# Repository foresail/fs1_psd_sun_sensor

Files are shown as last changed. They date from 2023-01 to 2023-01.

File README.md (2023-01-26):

# Foresail-1 PSD Sun Sensor

This repository contains the public available design files for the PSD sun sensor designed for the Foresail-1 Cubesat.

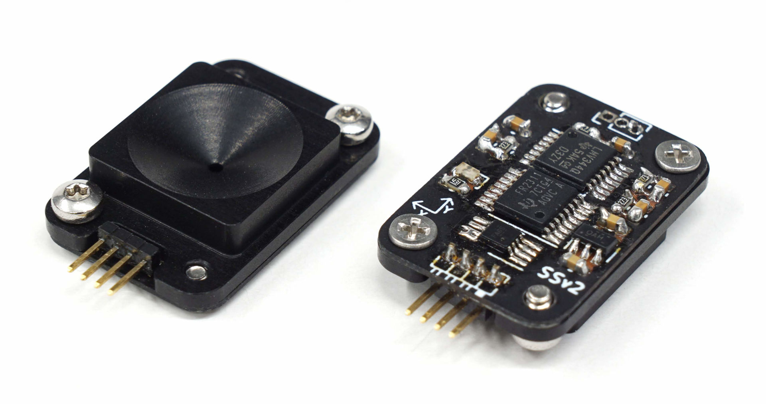
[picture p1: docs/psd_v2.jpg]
PSD Sun Sensor Prototype v2


The general characteristics of sensor design are:
- Dimensions: 24 mm × 16 mm × 6 mm
- Mass: 4 grams
- Panel mountedable into 14x14 mm hole with two M2 screws.
- Electrical connection by soldering on the panel PCB or by harness.
- FOV: ~100 degrees, resolution: 0.13°, accuracy: ±1° (discussed in the desgin document)
- Refresh rate up to 100 Hz. (Sampling time: 4 ms + communication overhead)
- Can provide following data products:
    - Raw current measurements
    - Point & intensity measurements
    - Sun vector & intensity measurements
    - Angles & intensity measurements
- I2C digital serial interface (hardware version 3)
- RS-485 digital interface (hardware version 4)
- Low power consumption < 4 mW when active
- Nominal operating voltage: 3.6 - 3.8V: Can be extened easily to 2.0 – 5.5 V.

## Documentation

- [FS1 ADCS PSD Sun Sensor Design Document](docs/FS1_ADCS_PSD_Sun_Sensor_Design_Document.pdf)
- [Version 3 schematic (I2C variant)](v3/v3_schema.pdf)
- [Version 3 firmware source code](v3/fw)
- [Version 4 schematic (RS-485 variant)](v4/v4_schema.pdf)
- [Calibration and test tools for PC](calibration)
- [Mechanical design files](mechanical)

## Licence

The design is licenced under [CERN Open Hardware Licence Version 2](LICENCE)

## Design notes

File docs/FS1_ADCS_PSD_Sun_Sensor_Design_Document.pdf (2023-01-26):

Version date: 2023-01-26
Responsible: Petri Niemelä
Document name: FS1 ADCS PSD Sun Sensor Design Document

# Foresail-1

# PSD Sun Sensor Design Document

# Aalto University

## Department of Electronics and Nanoengineering

## PSD Sun Sensor Design Document

FS1 ADCS PSD Sun Sensor Design Document
Page: 2 / 22

### Authors

Name | Worked with parts
Petri Niemelä | The whole document

Approved by

______________________________________

Page: 3 / 22

### Table of Contents

1 General | 4
1.1 Scope | 4
1.2 Applicable Documents | 4
1.3 Reference documents | 4
1.4 Abbreviations and acronyms | 4
2 Sensor Design | 5
2.1 Performance | 6
2.2 Sun vector estimation | 9
3 Electrical Design | 10
3.1 Electrical Interface | 10
3.2 Microcontroller | 10
3.2.1 Radiation Hardening | 11
3.3 Transimpedance Amplifiers | 11
3.4 Analog Digital Converter | 14
3.5 Power supply | 14
3.6 I2C bus isolation | 14
3.7 Operating environment | 15
4 Mechanical Design | 16
4.1 Mechanical Interface | 16
5 Digital interface | 17
5.1 I2C Commanding Protocol | 17
5.2 RS-485 Commanding Protocol | 17
5.3 Command set | 17
6 References and further reading | 19
7 Appendices | 21
7.1 Schematics | 21
7.2 Bill of Material | 21
7.3 PCB layout | 22

Page: 4 / 22

## 1 General

### 1.1 Scope

This document represents a detailed design of the PSD Sun Sensor designed for FORESAIL-satellites. This document applies for hardware version v3 (I2C variant) and v4 (RS-485 variant).

The public design files can be found from Github-repository: https://github.com/foresail/fs1_psd_sun_sensor

### 1.2 Applicable Documents

[AD-01] FS1 ADCS PSD Sun Sensor Prototype Test Plan (https://docs.google.com/document/d/1LfsjXxHAqfksmW_5qAY_K_lkndrjo7vK9R7hFGDcjuA/edit)

[AD-02] FS1 ADCS PSD Sun Sensor Qualification Test Report template (https://drive.google.com/open?id=1y2Mrd9W40DUWGKvcDPNy5vSXA1CmaDOZ_xgLSq9taWw)

### 1.3 Reference documents

[RD-01] Hamamatsu S5990-01 Two-Dimensional PSD
datasheet: https://www.hamamatsu.com/resources/pdf/ssd/s5990-01_etc_kpsd1010e.pdf

[RD-02] Texas Instrument’s MSP430FR231x Mixed-Signal Microcontrollers datasheet: http://www.ti.com/lit/ds/slase58d/slase58d.pdf

[RD-03] Texas Instrument’s OPAx340 Single-Supply, Rail-to-Rail Operational Amplifiers datasheet: http://www.ti.com/lit/ds/symlink/opa4340.pdf

### 1.4 Abbreviations and acronyms

ADC | Analog-to-Digital Converter
FRAM | Ferroelectric Random Access Memory
FOV | Field Of View
MCU | Microcontroller
PCB | Printed Circuit Board
PSD | Position Sensitive Detector/Device
TIA | Transimpedance Amplifier
WDT | Watchdog Timer

Page: 5 / 22

## 2 Sensor Design

The PSD sensor (Position Sensitive Detector/Device/Diode) is a light sensitive photodiode which produces a small current when exposed to light. The PSD differs from the normal photodiode by having four cathodes and one anode for one single large detector area. When the sensitive area is illuminated with a relatively small spot of light the produced currents are distributed depending on the position of the light spot. When the light spot is created using a pinhole structure the sensor can be used to measure direction/angle of the incoming light and thus the concept can be applied for making a sun sensor.

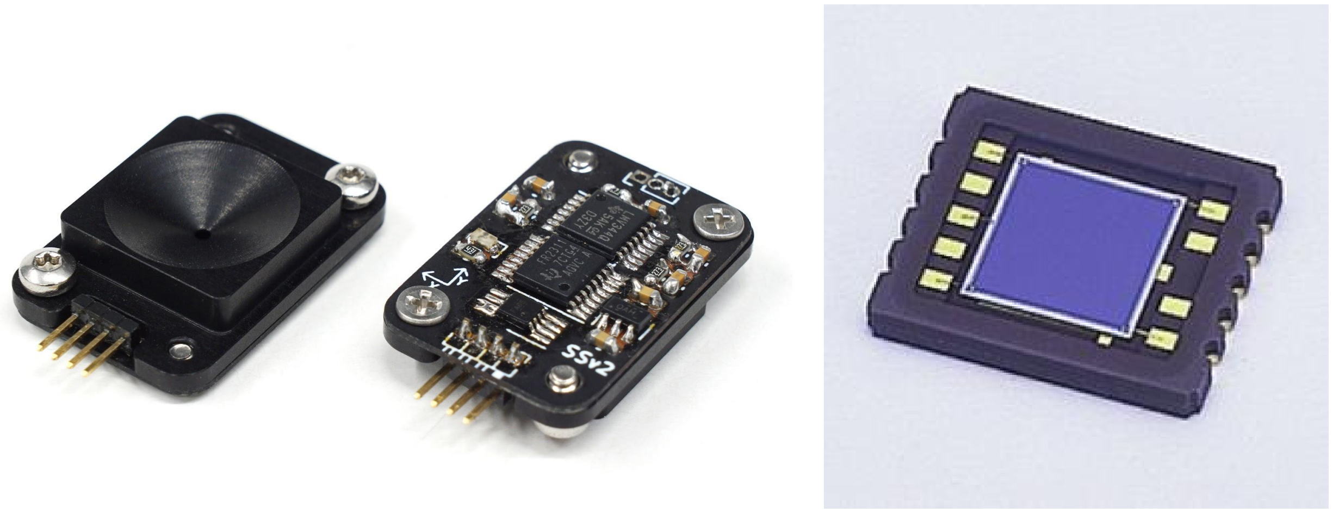
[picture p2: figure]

Figure 1: PSD Sun Sensor version 2 and Hamamatsu S5990-01 Position Sensitive Device

The used PSD, Hamamatsu S5990-1, (In Figure 1) is so called tetra-lateral type (pin-cushion type) that delivers improved position detection and linearity compared to other similar diodes. The sensor has a large 4 × 4 mm active area. [RD-01]

PSD sensors advantages in sun sensor application can be considered: simple electrical and mechanical design and easily achievable large Field of View (FOV). The sensor design's largest disadvantage is its sensitivity for straylight meaning that the sensor cannot discriminate between direct sunlight and reflected sunlight. Reflections, for example from moonshine or earthshine, cause bias error which cannot be easily eliminated from the measurements. Effect of this will be discussed later in detail.

The general characteristics of sensor design are:
- Dimensions: 24 mm × 16 mm × 6 mm
- Mass: 4 grams
- Panel mountable into 14x14 mm hole with two M2 screws
- Extension behind the panel: 3.1 mm
- Electrical connection by soldering on the panel PCB or by harness.
- FOV: ~100 degrees, resolution: 0.13°, accuracy: ±1° (discussed in the following sections)
- Refresh rate up to 100 Hz. (Sampling time: 4 ms + communication overhead)
- Can provide following data products:
- Raw current measurements
- Point & intensity measurements
- Sun vector & intensity measurements
- Angles & intensity measurements

Page: 6 / 22

- I

2C digital serial interface (applicable for hardware version 3)
- Maximum bus speed 400 kHz at 3.3V logic level.
- I

2C address can be configured via the command interface.
- The I²C bus is isolated when the sensor is unpowered.
- RS-485 digital interface (applicable for hardware version 4)
- Follows reduced Foresail multi-drop RS-485 protocol definition
- TBD
- Low power consumption < 4 mW
- Sleep: 0.45 mA @3.6 V
- Sampling: 0.9 mA @3.6 V
- Peak sampling: TBD mA @3.6V
- In-rush current: TBD mA @3.6V
- Operating voltage: 2.0 – 5.5 V
- The standard version has a 3.3V LDO and designed operating voltage is around 3.6V.
- MSP430 can operate with voltages down to 1.8 V.

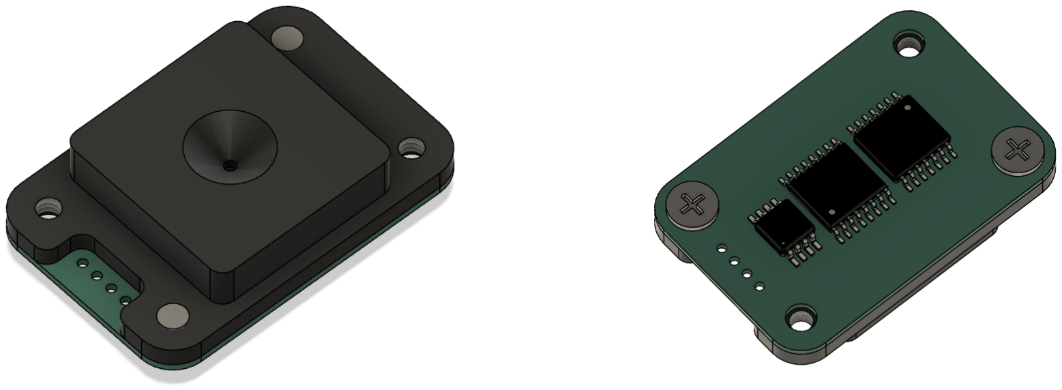
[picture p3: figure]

Figure 2: Front and back side of the PSD Sun Sensor assembly from CAD program.

### 2.1 Performance

The performance (FOV and accuracy) of the sensor is mainly determined by the geometry of the pinhole structure. The pinhole geometry is illustrated in the following figure. By adjusting the distance of the pinhole from the sensor. On the Foresail-1 PSD Sun Sensor the distance from photodiode to pin hole is 1.50 mm.

Page: 7 / 22

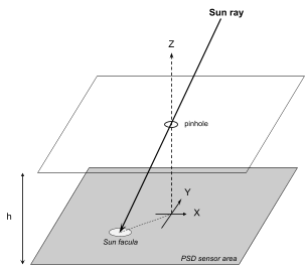
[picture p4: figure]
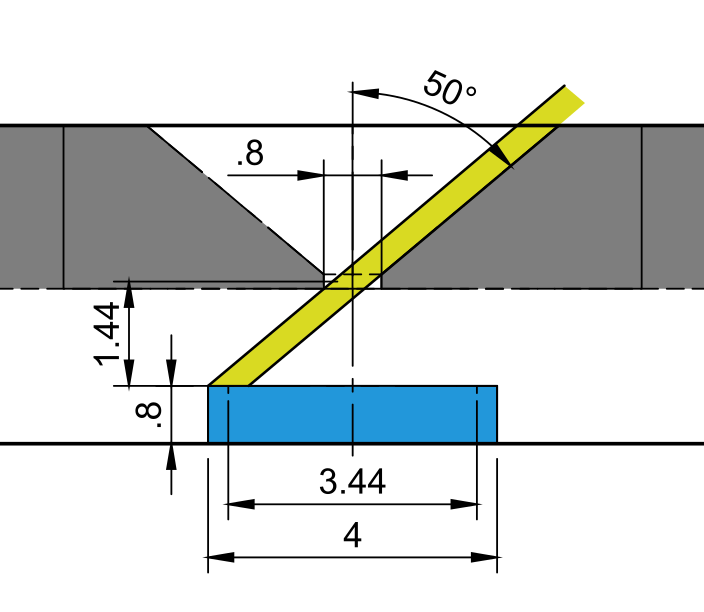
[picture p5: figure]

Figure 3: On left the sensor’s pinhole geometry illustrated in 3D. On the right the sensor’s actual pin hole geometry with dimensioning.

Field of View:
The maximum field of view of the sensor is determined by its tan( FoV/2 ) =

0.5*(w − d)
ℎ | =

0.5 * 3.44 mm
1.44 mm

⇒ FoV = 100°
In practice the sensor has an even larger FOV. (see calibration results)

Resolution:
When using 10 bits (1024 counts) per channel and because there are two channels per axis, each axis is “sampled” in 11-bit resolution. Thus, at the center of the sensor the theoretical resolution is:

θ = atan(

| (3.44 mm / 1024)
| 1.44 mm

) ≃ 0. 134°

This resolution improves when moving toward the edge of the sensor. Smaller angle changes in the Sun direction causes larger changes in light spot position. At the edge the theoretical resolution is:

θ = atan(

0.5 * 3.44 mm
1.44 mm

) − atan(

0.5 * 3.44 mm * 511/512
1.44 mm

) ≃ 0. 055°

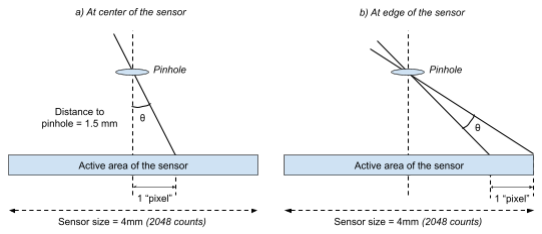
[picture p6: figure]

Figure 4: Resolution estimated using simplified pin hole geometry.

In theory, the resolution doesn’t depend on the size of the light spot until the light spot is clipped by

Page: 8 / 22

the edge of the active area of the sensor. The output currents and the current distribution depends on the intensity of the light and the “mass center” of the light. If the light spot size is increased its mass center stays the same. Only the intensity (amount of light passing through the pinhole) changes. The sensor’s gain can be adjusted using for any pinhole

Real accuracy:
In theory the sensor could achieve better than 0.15° accuracy but in practice the accuracy is not that good and it is affected by numerous error sources. In this section some of those error sources are analyzed. In practice the resolution of PSD based sensors varies between around 1 - 5°. If someone claims better accuracy (with similar FOV and single sensor) than this when using the same sensor technology, they most likely lie or don't tell the whole truth.

Error sources:
1) The sensor cannot differentiate between different sources of light: Sun, moon, Earth’s Albedo, specular reflections from the Earth’s surface. Discussed in detail in the next section.
2) The pinhole structure is not a perfect pinhole. Incoming light can reflect from the edge hole and cast a second light spot. Black anodisation aims to cope with this problem.
3) At high angles the cover glass can refract the light spot. This effect can be partially calibrated.
4) The light spot can reflect from the cover glass and bounce inside the sensor. The error caused by the reflections inside the sensors are tried to minimize by anodizing the sensor cover black.
5) The response of the PSD is not completely linear aka current distribution doesn’t map the light spot position perfectly. This happens both in axis and diagonally mapping. Hamamatsu’s tetra-lateral type (pin-cushion type) PSD aims to compensate for this.
6) The ADC is not perfect and it has noise on its results. According to the MCU’s datasheet ADC Effective error in 10-bit mode is ±2 LSB (least significant bits). Based on this the accuracy is less than 0.3°. ADC noise could be reduced by using oversampling because the sampling noise is gaussian by its nature. This is not seen beneficial because other error sources are more dominant and multi-sampling would just slow down the sampling.
7) Thermal expansion of the components is not considered. The surface temperature of the satellite can vary between -40°C and 40°C. The sensor cover should have a mirror finish on its front side to minimize heat load.
8) Sensor mounting on the satellite structure easily introduces a significant systematic error which is larger than the accuracy of the sensor. Calibrating the sensor position/orientation relative to the satellite’s coordinate system should be performed after final assembly but such test setup is not simple.

Effect of the straylight:
PSD sun sensor's greatest disadvantage is its incapability to differentiate between different light sources. The currents generated by different light sources (Sun, Earth, Moon shine and specular reflections from Earth’s surface) sums up together and cannot be separated from each other. Thus, Earth’s and Moon’s albedos add a bias error into Sun direction estimation if they are visible at the same time. Because each satellite’s face has a dedicated sun sensor and only the strongest signal is taken into consideration in sun vector determination, the Earth’s albedo affects the sun vector measurements only when the Sun and Earth are inside the same 90° FOV “pyramide”. This happens

Page: 9 / 22

when the satellite is above 66’th latitude (north or south) and ±24° around the termination zone. The influence of Earth’s albedo is constantly on sun synchronous orbit, which Mean Local Time of the Ascending Node (LTAN) is between 04:24 - 08:36 and 16:36 - 19:24. These regions are illustrated in the Figure 5.

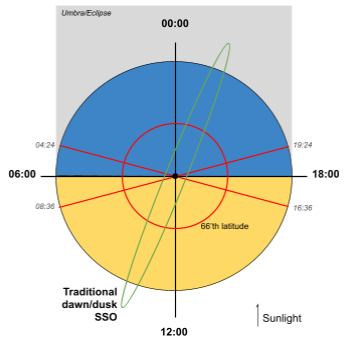
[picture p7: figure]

Figure 5: Orbit regions where PSD’s operation is affected by Earth’s albedo.

The effect of Earth’s albedo to the accuracy of PSD sun sensor is greatly discussed in Rober Valner’s bachelor’s thesis: http://dspace.ut.ee/bitstream/handle/10062/30981/Robert_Valner.pdf In his thesis he concludes that: “the net uncertainty of the measurements of the sensor is 2.5° with coverage probability of approximately 95%”

Intensity accuracy:
The intensity measurement of the sensor is relative and should not be used as absolute measurement. The sensor’s intensity output is the average of each channel's output in range from 0 to 1024. The reading highly depends on the sensor’s temperature due to photodiodes efficiency characteristics and temperature drift of the voltage reference.

The intensity reading itself could be also used to determine the sun angle using inverse cosine law and with temperature compensation using the MCU’s temperature sensor could provide better absolute accuracy but this is implemented because it’s not seen beneficial for an attitude control system as whole. The linearity of the intensity measurement is not known.

What could be improved?
Possible methods to improvement accuracy:
1. More sensors with smaller FOV
2. Add UV bandpass filter to remove the effect of albedo and specular reflections.

### 2.2 Sun vector estimation

The determination of the sun vector from multiple sun sensors can be done using following simple algorithm:

Page: 10 / 22

meas = get_all_sun_vectors()

sun_detected = false
sensor_i = arg_max(meas.intensity)
if meas[sensor_i].intensity > detection_threshold:
sun_direction = apply_rotation(sensor_i, meas[sensor_i].vector) sun detected = true

## 3 Electrical Design

The electrical design of the sensor is very simple. It consists of a PSD sensor itself (aka four channel photodiode), four transimpedance amplifiers and a MCU for analog to digital conversion and digital communication.

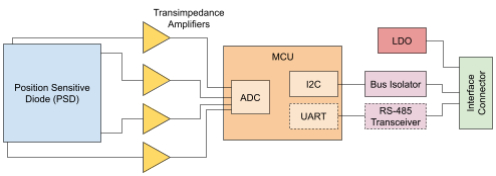
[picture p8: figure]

Figure: Block diagram of the sensor's electrical components and their connections.

### 3.1 Electrical Interface

The sensor’s electrical interface is described in the table below.

Table: Sensor pinout
Pin number | Pin name on version 3 | Pin name on version 4
1 | GND | GND
2 | VCC | VCC
3 | I2C SDA | RS-485 DATA+
4 | I2C SCL | RS-485 DATA-

On the PCB the electrical connection is done to the 1.27 mm pitch pin 4 hole connector footprint. To this footprint the electrical connection can be done by directly soldering the sensor on a PCB panel using a right angle 1.27mm pin header or by soldering a pigtail cable on it.

### 3.2 Microcontroller

The PSD sun sensors’ MCU is Texas Instrument’s MSP430FR2311IPW16. MCU’s important features are: [RD-02]

Page: 11 / 22

- Small TSSOP-16 package
- Runs at 4 MHz
- 3.75KB of Program FRAM (Radiation Resistant and Nonmagnetic) + 1KB of RAM
- Internal 1.2V voltage reference
- 8 channel 10-Bit Analog-to-Digital Converter (ADC) with internal 1.5V voltage reference
- Optimized low power modes (32nA in shutdown)
- Wide support for serial communication protocols such as I

2C, UART etc.
- Internal brown-out detection circuit

The selected MCU has also internal opamp which could have been used for something.

### 3.2.1 Radiation Hardening

Following radiation hardening are considered in the design:

### 1. Usage of system FRAM memory:

The selected MCU uses FRAM technology for storing its firmware. The FRAM technology is known from its radiation hardness on a memory cell (SEU: Single Event Upsets). This doesn’t ensure complete radiation hardness against other types of single events. Single events can also happen in the memory controllers etc.

Also the sensor is vulnerable to destructive single events burnouts if no latching.

The dose tolerance of the MCU is not known and it could be generalized outside of a single batch.

### 2. Watchdog Timer:

Watchdog resets the MCU every ~40 seconds if the main loop stops running. Heartbeat timer tries to wake up the processor every 70 ms to execute the main loop.

### 3. Register refreshing by resetting:

Sensor initializes itself every 2 minutes in nominal state to refresh all internal peripheral registers.

### 3. Component-level power cycling:

The opamp’s power is supplied from MCU’s IO-pin which works as current limiter and load switch and it can be used to cycle on every reset.

### 4. Sensor Aluminium shielding

At the surface of the satellite, the sensor experiences a harsher radiation environment compared to the rest of the electronics on board inside the radiation shielding. To compensate this a little bit, the thickness of the aluminum sensor cover has not been minimized to give some protection against total dose effects. The only way to improve this more is to move the electronics beside the PSD photodiode itself inside the satellite.

### 3.3 Transimpedance Amplifiers

For PSD sensor current measurement the sensor board has four transimpedance amplifiers (TIA) to perform current-voltage conversion with predefined gain. The amplifier gain is set by the external resistor and adjusted depending on illumination levels, hole size etc. Photodiodes are in zero reverse bias configuration for improved sensitivity at low intensities. Additionally, a filtering capacitor is placed parallel on the feedback loop to cut-off frequencies above 100 Hz.

Page: 12 / 22

When the current is zero the opamp outputs the reference voltage and higher the current lower the output voltage is. The output voltage can be then measured by the ADC. MSP430’s internal voltage reference (VREF+) is used for the opamp. The precision of the voltage reference doesn’t affect the overall point position measurements. The possible reference voltage drift affects only absolute intensity measurements and is the same for all the channels. The point position is calculated from the differences of absolute current measurement as defined in equation X, and thus, possible reference voltage drift won’t affect sun vector accuracy. The absolute illumination is not sure for sun vector determination. Also, the diode’s leakage current will vary based on the temperature.

On hardware version 4 (RS-485 variant), the MSP430’s internal voltage reference cannot be used due to pin mapping collision with an UART pin required for RS-485 transceiver. Thus, an external voltage reference is required for the opamps. There are no real requirements for the reference other than voltage should be such that the opamp doesn't need to drive till the rail voltage. Absolute stability is not required because the intensity measurements are already relative by their nature and the reference is shared between the channels. Also the voltage reference is connected to very high impedance (only opamps inputs), so the current draw is negligible. Thus, to keep the BOM and PCB layout simple a simple 1:1 resistor divider was chosen to generate 1.65 V reference. The resistor divider as voltage reference is sensitive for source voltage but in this case the 3.3V source voltage is regulated very close to the divider itself.

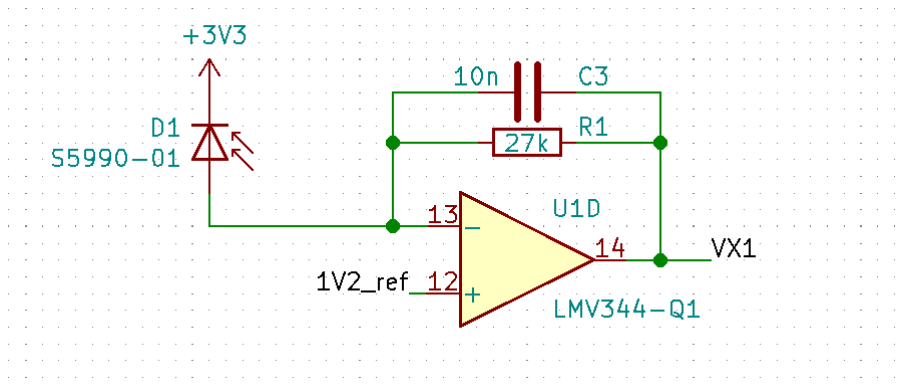
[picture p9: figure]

Figure 6: Simplified circuit diagram of a transimpedance amplifier.

The chosen operational amplifier is automotive quality LMV344-Q1 quad rail-to-rail output CMOS operational amplifier in small TSSOP-14 package [RD-03]. The opamp has relatively narrow bandwidth (1 MHz), low power consumption 100 µA (typical). Measured current consumption in dark: 230 µA. (0.83 mW @3.6 V)

Opamp’s positive rail is at 3.3 V and negative at GND. The opamp is powered from MCU’s GPIO pin thus can be turned to save even more power. This is possible due to the low power consumption of the opamp.

The response of the transimpedance amplifier circuit was simulated using LTspice simulation program. The simulation model is illustrated in Figure 7. The model was used to confirm the AC response of the filter (Figure 8). Also, an input waveform for the photodiode current source was generated using a simple Python script. The amplifier circuit’s time domain response when attach on a satellite spinning at 1 Hz can be seen in Figure 9.

Page: 13 / 22

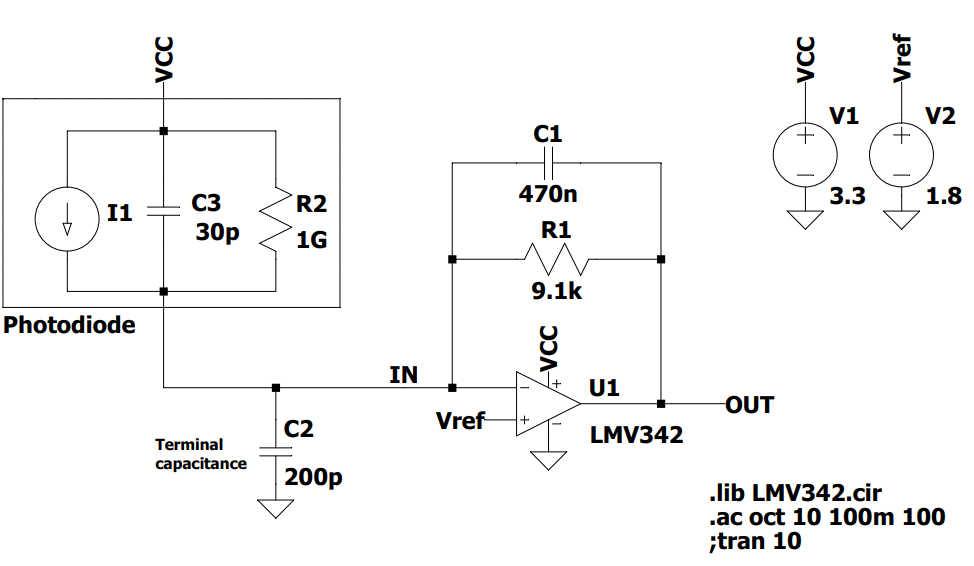
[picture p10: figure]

Figure 7: LTSpice model used to simulate the transimpedance amplifier transient and AC responses. (The used LMV342 opamp is identical LMV344 but has different number of channels)

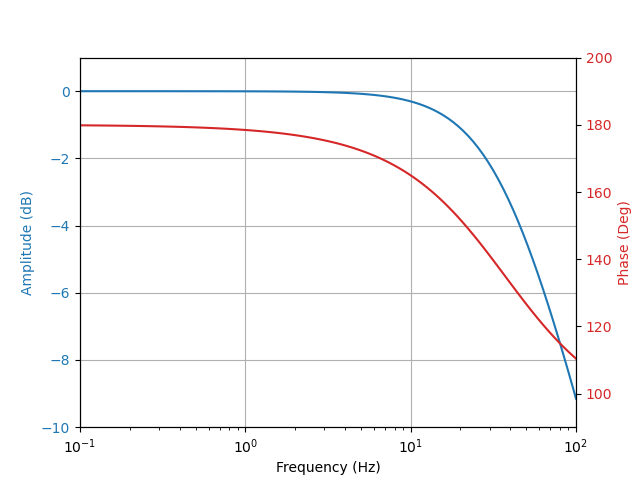
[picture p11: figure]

Figure 8: The AC response of the transimpedance filter. The -3dB cutoff frequency is around 37 Hz.

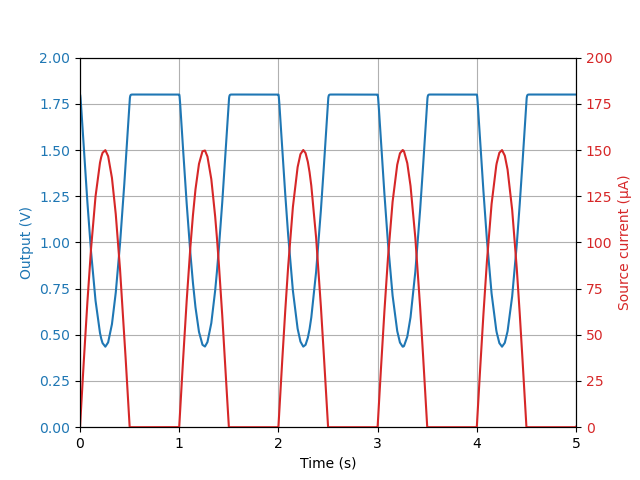
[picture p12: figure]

Figure 8: Transient response of the TIA for 1Hz (60 rpm) spin. The output voltage response is inverted compared to the produced current of the photodiode due to the reverse bias design. Small amount of smoothening can be seen on the trailing edge due to low pass filtering.

Page: 14 / 22

### 3.4 Analog Digital Converter

The analog to digital conversion is done using MSP430’s internal 8-channel 10-bit ADC and the analog lines are referenced against MSP430’s 1.2 V reference (VREF+) which is externally connected to ADC’s VEREF+ -pin.

The ADC samples the different voltage channels in sequence and not simultaneously. The small sample time difference is considered to be negligible for the precision of the sensor. For a satellite spinning at 1 Hz, the satellite attitude changes 1.1° during the 3 ms sampling time.

Temperature sensor: MSP430 has an internal temperature sensor which is connected to ADC’s channel 12. Temperature sensor voltage is compared to ADC’s internal 1.5 V reference. The maximum temperature the sensor can measure is roughly 170°C. Above this temperature the sensor voltage goes above 1.5 V.

ADC count to temperature is thus coefficient:
3. 35 mV/°C ⇒ (1500mV / 1024 counts) / 3. 35mV/°C = 4. 37° dC/count

Equation on the MCU:
T(°dC) = (ADCcount − calib) / 4 °dC/count + 300°dC

### 3.5 Power supply

The sensor is designed to take 3.6 V input voltage and has 3.3 V low dropout voltage (LDO) regulator on board. Lower voltages are possible down to 2.5V with the same opamp or down to 1.5 V the opamp is changed to a similar kind of with lower input voltage rating. The LDO can be also bypassed with a 0-ohm resistor if wanted.

### 3.6 I

### 2C bus isolation

Sun sensor uses SN74TVC3306 bus level translation IC as I

2C bus isolator to prevent stalling the I

2C bus when the sensor is not powered. The isolator also prevents the sensor from being powered via the SDA/SCL lines due to low power consumption of the MSP430 processor. The isolator IC is basically three individual NMOS transistors (also called dual voltage clamp) and can be considered robust design for higher radiation environment. The down side of this type of isolator is the 3.5 ohm high’ish series resistance.

Page: 15 / 22

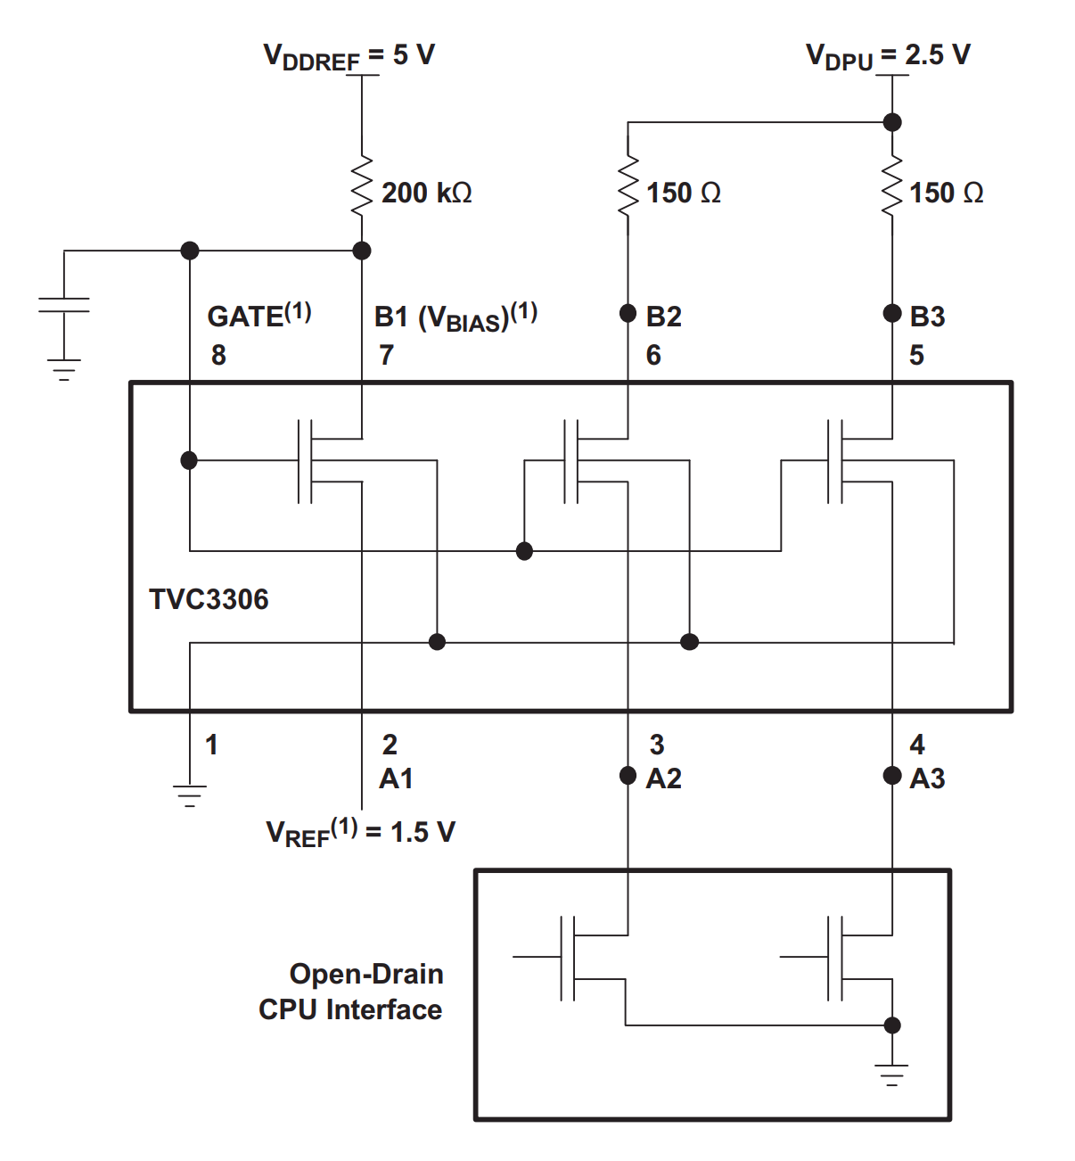
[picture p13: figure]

Figure 9: Internals of the SN74TVC3306 IC used for the I2C bus

### 3.7 Operating environment

The PSD sun sensors are expected to encounter large temperature variations in the low earth orbit conditions on the surface of the satellite. On the surface of the satellite, sensors are exposed to direct sunlight and cold space in turns with very little thermal inertial and poor thermal conduction to the rest of the satellite's structure. It has been estimated that the surface temperatures of the cubesat in LEO will at least vary from -20 to 30 °C on every orbit and in the worst case -40°C to 60°C.

The recommended operating temperature ranges for each component can be seen in the following table. The most limiting recommended temperature range is for Hamamatsu's PSD diode whose lower temperature limit is -20°C. Low temperatures doesn’t inherently degrade the electrical performance of a diode but the diode’s packaging method might be the reason for the lowered rating. (Maybe the manufacturer hasn’t just performed the qualification test for lower temperatures.) There are no huge concerns to suspect that the diode would fail right after -20°C. Also, thermal vacuum verification tests with -40 to +100°C temperature range are performed for all the PSD sun sensors assemblies at subsystem level.

Table: Off-the-self component environment ratings
Component | Recommended Operating Temperature
Hamamatsu S5990-01 | −20°C to +60°C
MSP430FR2311IPW16 | −40°C to +80°C
LMV344-Q1 | −40°C to +125°C
TLV71333P-Q1 | −40°C to +125°C
SN74TVC3306 | −40°C to +80°C

Page: 16 / 22

The sensor PCBs are ordered with higher Epoxy glass transition temperature (Tg=170-180°C) to make sure the PCB can tolerate high temperature cycles and won’t fracture or de-laminate due to material expansion.

Note: A single case of sensor stopping working at temperatures higher than 50°C has been observed. The root cause of the problem was never investigated but it was clearly an analog side failure. The sensor recovered by itself when the temperature decreased below 50°C.

## 4 Mechanical Design

Sensor’s main structural component is the aluminum sensor cover which also works as the pin hole structure for the photodiode. The 0.5mm thick back PCB attaches to the sensor cover using two M2x2 screws and the whole assembly has been designed to be mounted on the panel (Aluminum plate or PCB).

The sensor cover has four M2 threaded holes in total. Two of these are used for attaching the PCB to the cover and other two are used to attach the whole assembly to the panel. Mounting to the panel can be done for example with two M2x4 screws. In Figure 10 the sensor’s overall dimensions and the locations of the attachment holes can be seen.

Either of the diagonals can be used for attaching the PCB and for sensor mounting. See preferred from Figures 1 and 2.

### 4.1 Mechanical Interface

The sensor’s mechanical interface can be seen in the figure below.

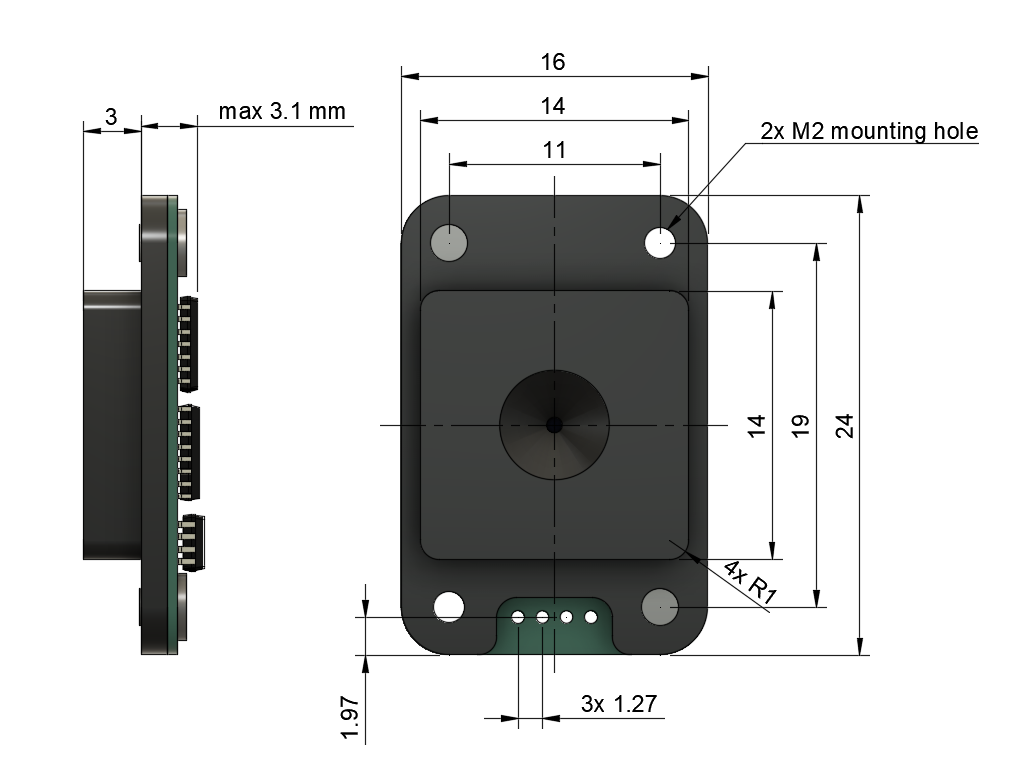
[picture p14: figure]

Figure 10: Required panel cut out for the module.The preferred holes for panel mounting are top-right and bottom-left holes.

Page: 17 / 22

The sensor is designed to be mounted on a 14x14mm size rectangular hole whose corner has 1mm rounding.

Note: Due to the small size of the sun sensor, the mounting/remounting accuracy of the sensor is not very high. Thus, the sensor's relative orientation to the satellite’s reference frame should be calibrated after the final integration.

## 5 Digital interface

This section defines the I²C and RS-485 digital interfaces and the command set over the bus.

### 5.1 I

### 2C Commanding Protocol

Sensor’s digital interface uses the I

2C protocol where the sensor works as a slave. Default I

2C
address is 0x6A and the slave address can be set when reprogramming the sensor or using the I

2C
commands. Sensor implements a simple I

2C protocol which follows the standard I

2C data structure
and defines the first transmitted byte as a command byte which identifies the command or the response. The protocol commanding and response structure are illustrated in Figure 6.

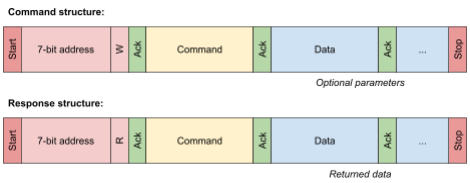
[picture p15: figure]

Figure 11: I²C command and response structures

Remarks:
- The default address range for the sensors is: 0x4A - 0x4F
- If the I²C master tries to read the response before the sensor is ready the slave will answer by sending 0xFF.

### 5.2 RS-485 Commanding Protocol

TBD

### 5.3 Command set

List of PSD Sun Sensor commands and their functionalities

Remarks:
- Commands which do not return a special data structure return a status code with status command code (0x01).
- All the multi byte integers are in little endian format (most significant byte is last).

Page: 18 / 22

- If there is no I²C communication on the bus in 2 seconds the MCU will turn off the opamp, voltage references and ADC to save power and unbiased the analog components.

0x01: Status
Read len: 1
Returns response code RSP_OK (0xF0) or RSP_SLEEP (0xF1).

0x03: Get Raw
Runs measurement sequence and returns raw current readings. Read len: 9

typedef struct { // size() = 8 bytes
uint16_t vx1; // Range: 0 - 1024 uint16_t vx2; // Range: 0 - 1024 uint16_t vy1; // Range: 0 - 1024 uint16_t vy2; // Range: 0 - 1024 } raw_measurements_t;

0x04: Get Position
Runs measurement sequence and returns measured light sport position and intensity.

typedef struct { // size() = 6 bytes
int16_t x; | // -1024 - +1024
int16_t y; | // -1014 - +1024
uint16_t intensity;
} position_measurement_t;

0x05: Get Angles
Runs measurement sequence and returns measured angles and intensity.

typedef struct { // size() = 6 bytes
int16_t ax; // Desidegrees int16_t ay;
uint16_t intensity;
} angle_measurement_t;
Note: The command uses 128 items look-up table and linear interpolation for angle calculation.

0x06: Get Vector
Runs measurement sequence and returns measured sun vector and intensity.

typedef struct { // size() = 8 bytes
int16_t x, y, z;
uint16_t intensity;
} vector_measurement_t;
Note: The reported vector is a direction vector toward the Sun aka signs of the X and Y point positions have been flipped.

0x07: Get All
Runs measurement sequence and returns all three data types listed above (raw, position, angles) Generally used for testing and verification purposes.

Page: 19 / 22

Read len: 21

0x08: Get Temperature
Return MCU temperature as 16-bit signed integer in desi-celsiuses aka 23.5°C = 235. Read len: 3 Sampling the temperature takes 1.54ms!

Note: If the temperature calibration offset is set to 0. This function will return the raw ADC count.

0x10: Set Calibration
Set calibration structure.

typedef struct {
int16_t offset_x, offset_y; int16_t height;
int16_t samples;
int16_t temperature_offset; } calibration_t;

0x11: Get Calibration
Returns the same calibration structure as described for “Set Calibration” command. Read len: 11

0x12: Set LUT
Set angle look up table values.
TBC

0xE8: Set I2C Address
Set a new I2C address for the sensor. To be applied a power cycling is required.

Note: Exact sampling time of sensor depends on the temperature due to temperar

## 6 References and further reading

References outside of the project:
1. P. Rodrigues, P. Ramos, “Design and characterization of A sun sensor for the SSETI-ESEO project”
http://citeseerx.ist.psu.edu/viewdoc/download?doi=10.1.1.515.3785&rep=rep1&type=pdf
2. C. Avsar, J. Lieb, W. Frese, M. Herfort, and S.Trowitzsch, “Verification of a new two-dimensional sun sensor with digital interface on a sounding rocket.” http://rexusbexus.net/wp-content/uploads/2015/06/tupex-3_sse_symposium_paper_expert_panel_version.pdf (http://rexusbexus.net/wp-content/uploads/2015/06/tupex-3_sse_symposium_paper_expert_panel_version.pdf)
3. L. Lin, Z. Sitong, T. Luyang, W. Dong,“Sun sensor design and test of a micro satellite”, https://www.jvejournals.com/article/17518
4. D. Faizullin, K. Hiraki, HORYU-IV team, M. Cho, “Optimization of a Sun Vector Determination for Pinhole Type Sun Sensor”,

Page: 20 / 22

http://oaji.net/articles/2017/1330-1507024153.pdf

Page: 21 / 22

## 7 Appendices

### 7.1 Schematics

Version 3

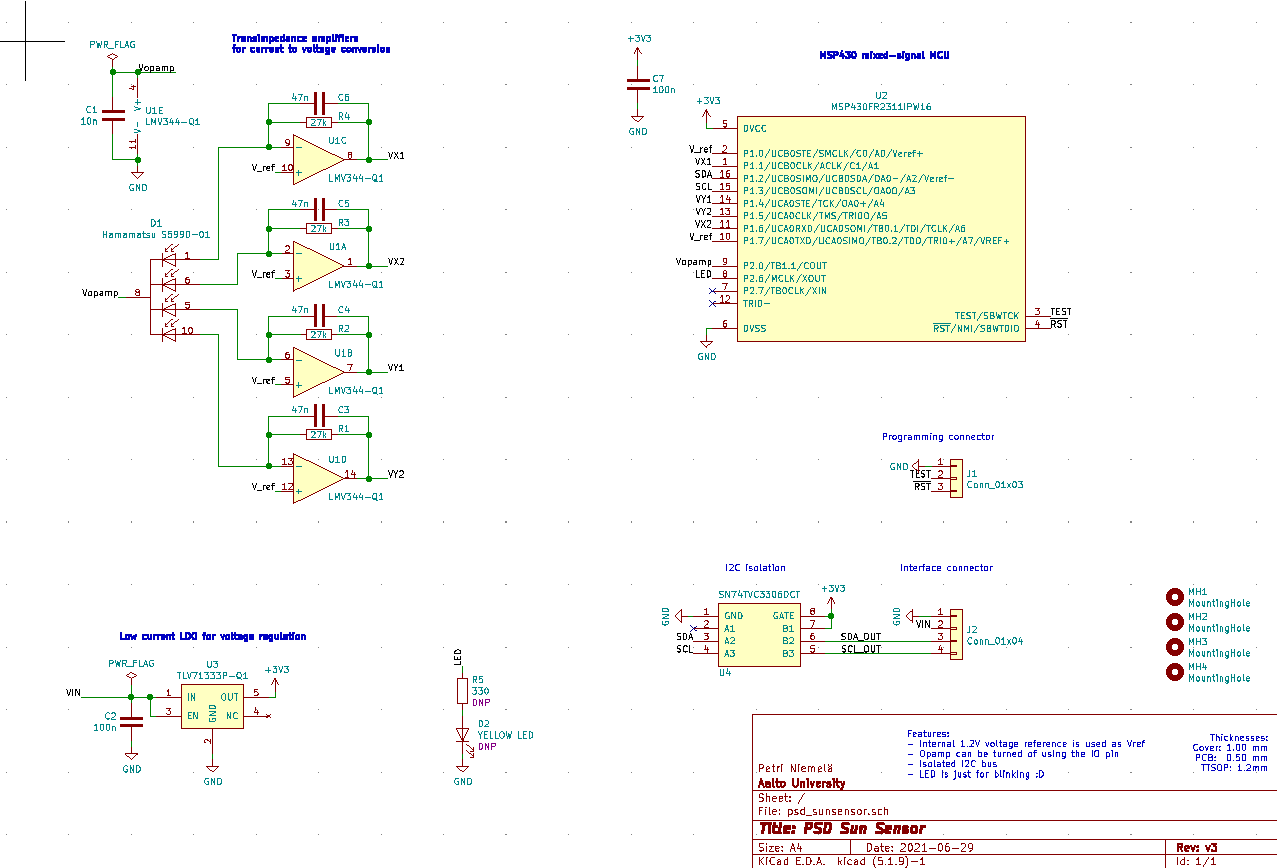
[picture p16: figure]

### 7.2 Bill of Material

Refs | Qty | Manufacturer | Name | Description/Comment
U1 | 1 | Texas Instruments | LMV344-Q1 | Automotive Grade Rail-to-Rail Output CMOS Op Amp
U2 | 1 | Texas Instruments | MSP430FR2311IPW16R | 16-bit Microcontrollers - MCU 16 MHz Ultra-Low-Power Microcontroller
U3 | 1 | Texas Instruments | TLV71333P | LDO Voltage Regulators Automotive Capacitor-Free 150mA Low-Dropout (LDO) Regulator
U4 | 1 | Texas Instruments | SN74TVC3306DCUR | Dual Voltage Clamp
C2,C7 | 2 | Generic | 100 nF 0603 SMD Capacitor | C0G and automotive grade

Page: 22 / 22

C1,C3, C4,C5, C6 | 5 | Generic | 10 nF 0603 SMD Capacitor | C0G and automotive grade
R1,R2, R3,R4 | 4 | Generic | 9k1 ohm 0603 SMD Resistor | Automotive grade
R5 | 1 | Generic | LED current limit 0603 SMD resistor | Do not populate on FM
D2 | 1 | Generic | Yellow 0603 SMD LED | Do not populate on FM
D1 | 1 | Hamamatsu | S5990-01 | Position Sensitive Detector (diode)
MH1, MH3 | 2 | Generic | A4 stainless steel M2 x 4mm pan head screw | Non magnetic!
MH2, MH4 | 2 | Generic | A4 stainless steel M2 x 2mm pan head | Non magnetic!

### 7.3 PCB layout

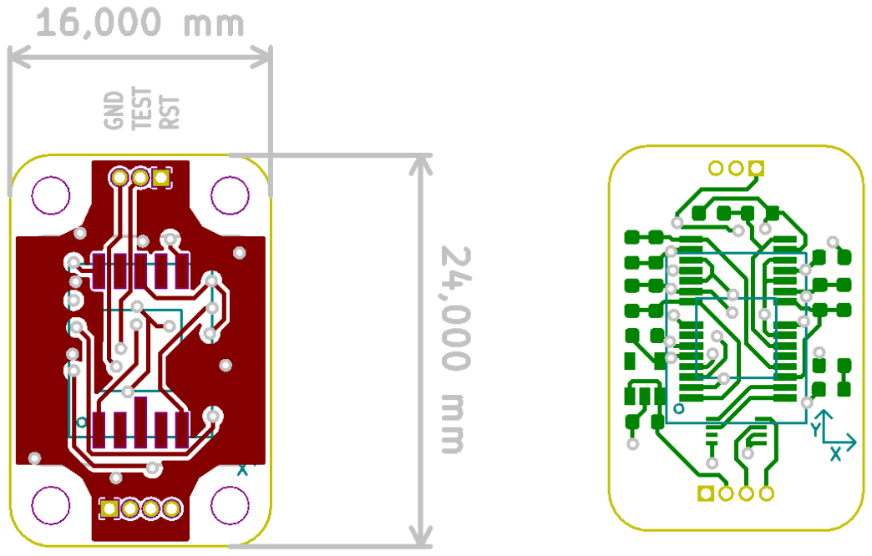
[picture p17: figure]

PCB front-side and back-side of hardware version 3

- Dimension: 16 mm × 24 mm
- PCB thickness: 0.5 mm

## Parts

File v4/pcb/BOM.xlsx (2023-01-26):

Mouser
References | Qty | Manufacturer | Name | Description | Mouser No. | Comments
U1 | 1 | Texas Instruments | LMV344-Q1 | Automotive Grade Rail-to-Rail Output CMOS Op Amp | 595-LMV344IPWRQ1
U2 | 1 | Texas Instruments | MSP430FR2311IPW16R | 16-bit Microcontrollers - MCU 16 MHz Ultra-Low-Power Microcontroller | 595-P430FR2311IPW16R
U3 | 1 | Texas Instruments | TLV71333P | LDO Voltage Regulators Automotive Capacitor-Free 150mA Low-Dropout (LDO) Regulator | 595-TLV71333PQDBVRQ1
U4 | 1 | Texas Instruments | SN74TVC3306 | Digital Bus Switch Ics, Dual Voltage Clamp | 595-SN74TVC3306DCUR
C2,C7 | 2 | Generic | X7R 100 nF 0402 Capacitor
C1,C3,C4,C5,C6 | 5 | Generic | X7R 10 nF 0402 Capacitor
R1,R2,R3,R4 | 4 | Generic | 9k1 ohm 0402 Resistor
R5 | 1 | Generic | 0402 LED current limit resistor
D2 | 1 | Generic | 0402 Yellow LED
Hamamatsu
References | Qty | Manufacturer | Name | Description |  | Comments
D1 | 1 | Hamamatsu | S5990-01 | Position Sensitive Detector

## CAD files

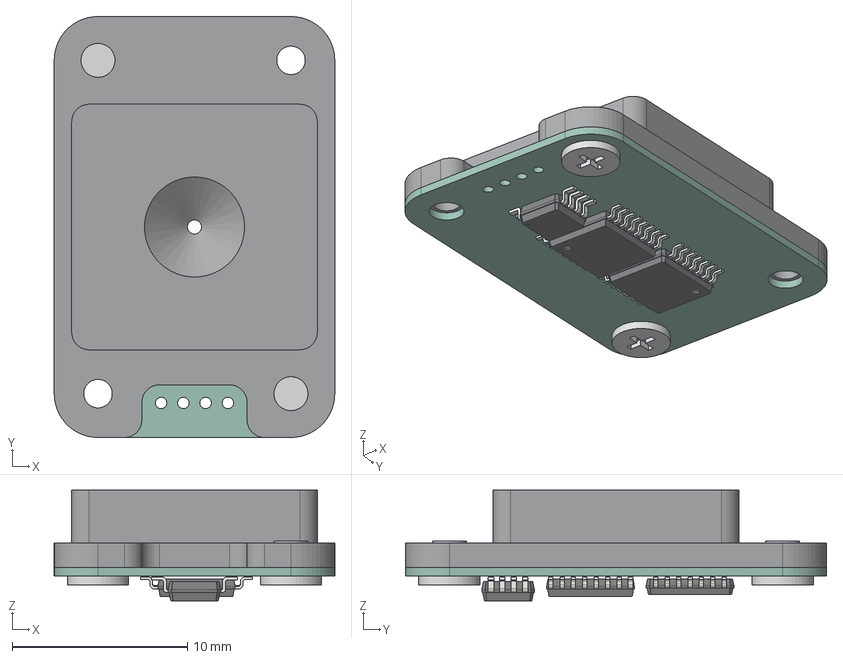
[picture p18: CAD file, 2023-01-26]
mechanical/psd_sun_sensor.step
16.0 x 24.0 x 6.30 mm
Simplfied PCB
Diode
Resin Window
Index Mark
Cover
M2x2 D3.5x0.5 x 2

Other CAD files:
mechanical/PSD Sun Sensor.f3z

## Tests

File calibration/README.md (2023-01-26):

# Calibration tools for PSD Sun Sensors

- `psd.py` has implementation to command the PSD Sun Sensor over FTDI 232H cable
   and also command line utility perform certain tasks from the command line.
- `meas.py` has calibration measurement routine. For sensors.
- `plot.py` has scripts to plot calibration measurements.
- `fit.py` has script to calculate calibration values from the measurements.
- `lut.py` has script to generate a tangent lookup table.

## PSD Test Tool

```
usage: psd.py [-h] [--addr ADDR] [--rate RATE] [--raw] [--point] [--vector] [--angles] [--all] [--temp] [--scan] [--calib] [--set_offset SET_OFFSET SET_OFFSET SET_OFFSET] [--set_temp SET_TEMP] [--set_addr SET_ADDR]

PSD test tool

optional arguments:
  -h, --help            show this help message and exit
  --addr ADDR, -a ADDR  Sensor I2C address
  --rate RATE, -r RATE  Sampling rate
  --raw                 Sample raw data
  --point               Sample point data
  --vector              Sample vector data
  --angles              Sample angle data
  --all                 Sample all data types
  --temp                Sample temperature types
  --scan                Scan responsive sensors
  --calib               Get calibration values
  --set_offset SET_OFFSET SET_OFFSET SET_OFFSET
                        Set position offset and height
  --set_temp SET_TEMP   Set temperature offset
  --set_addr SET_ADDR   Set sensor I2C address
```

**Examples:**
Scan the whole I2C address space for PSD Sun Sensors
```
$ ./psd.py --scan
```

Read sensor temperature
```
$ ./psd.py --temp
23.6 °C
24.0 °C
24.0 °C
24.0 °C
```

Read light point position
```
$ ./psd.py --point --adrr 0x4C
1303 -1303     2
1024 -2048     2
1024 -1365     3
1303 -1303     2
1024 -1024     3
1228 -1228     2
1592 -1592     2
1303 -1303     2
```

Change PSD I2C address
```
$ ./psd.py --addr [old] --set_addr [new]
```

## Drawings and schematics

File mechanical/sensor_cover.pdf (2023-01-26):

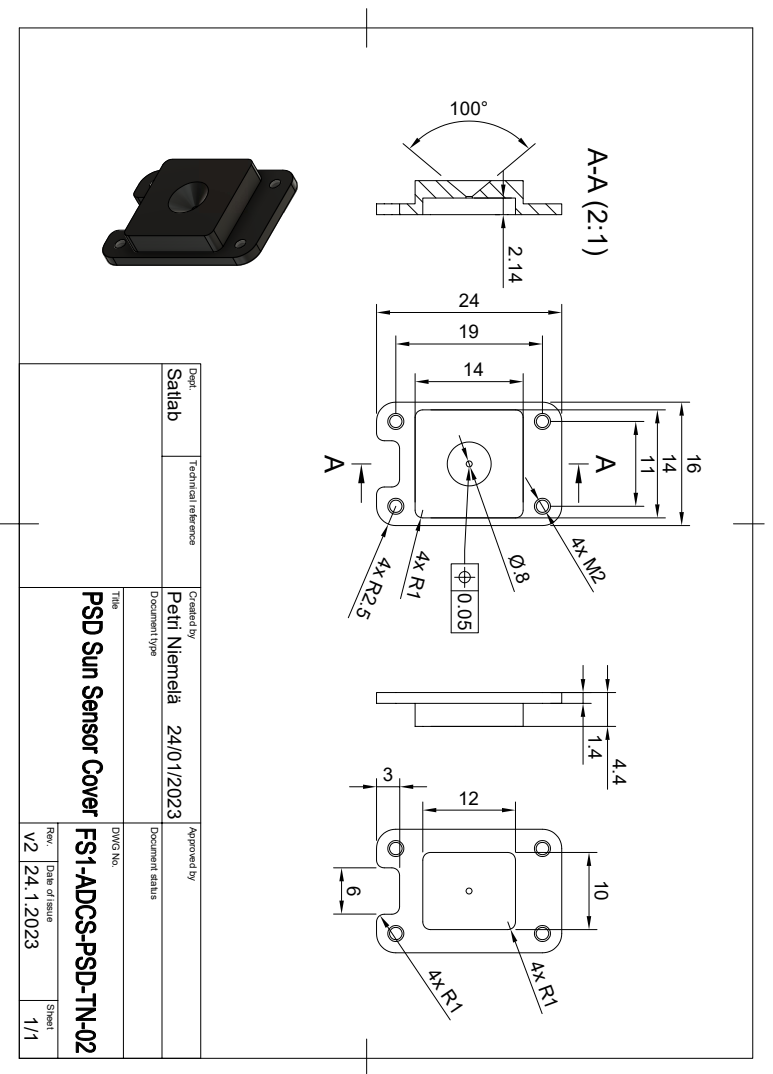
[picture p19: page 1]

Dept. Technical reference Created by Approved by Title DWG No. Document type Document status Rev. Date of issue Sheet 24.1.2023 v2 24/01/2023 1/1 Petri Niemelä Satlab

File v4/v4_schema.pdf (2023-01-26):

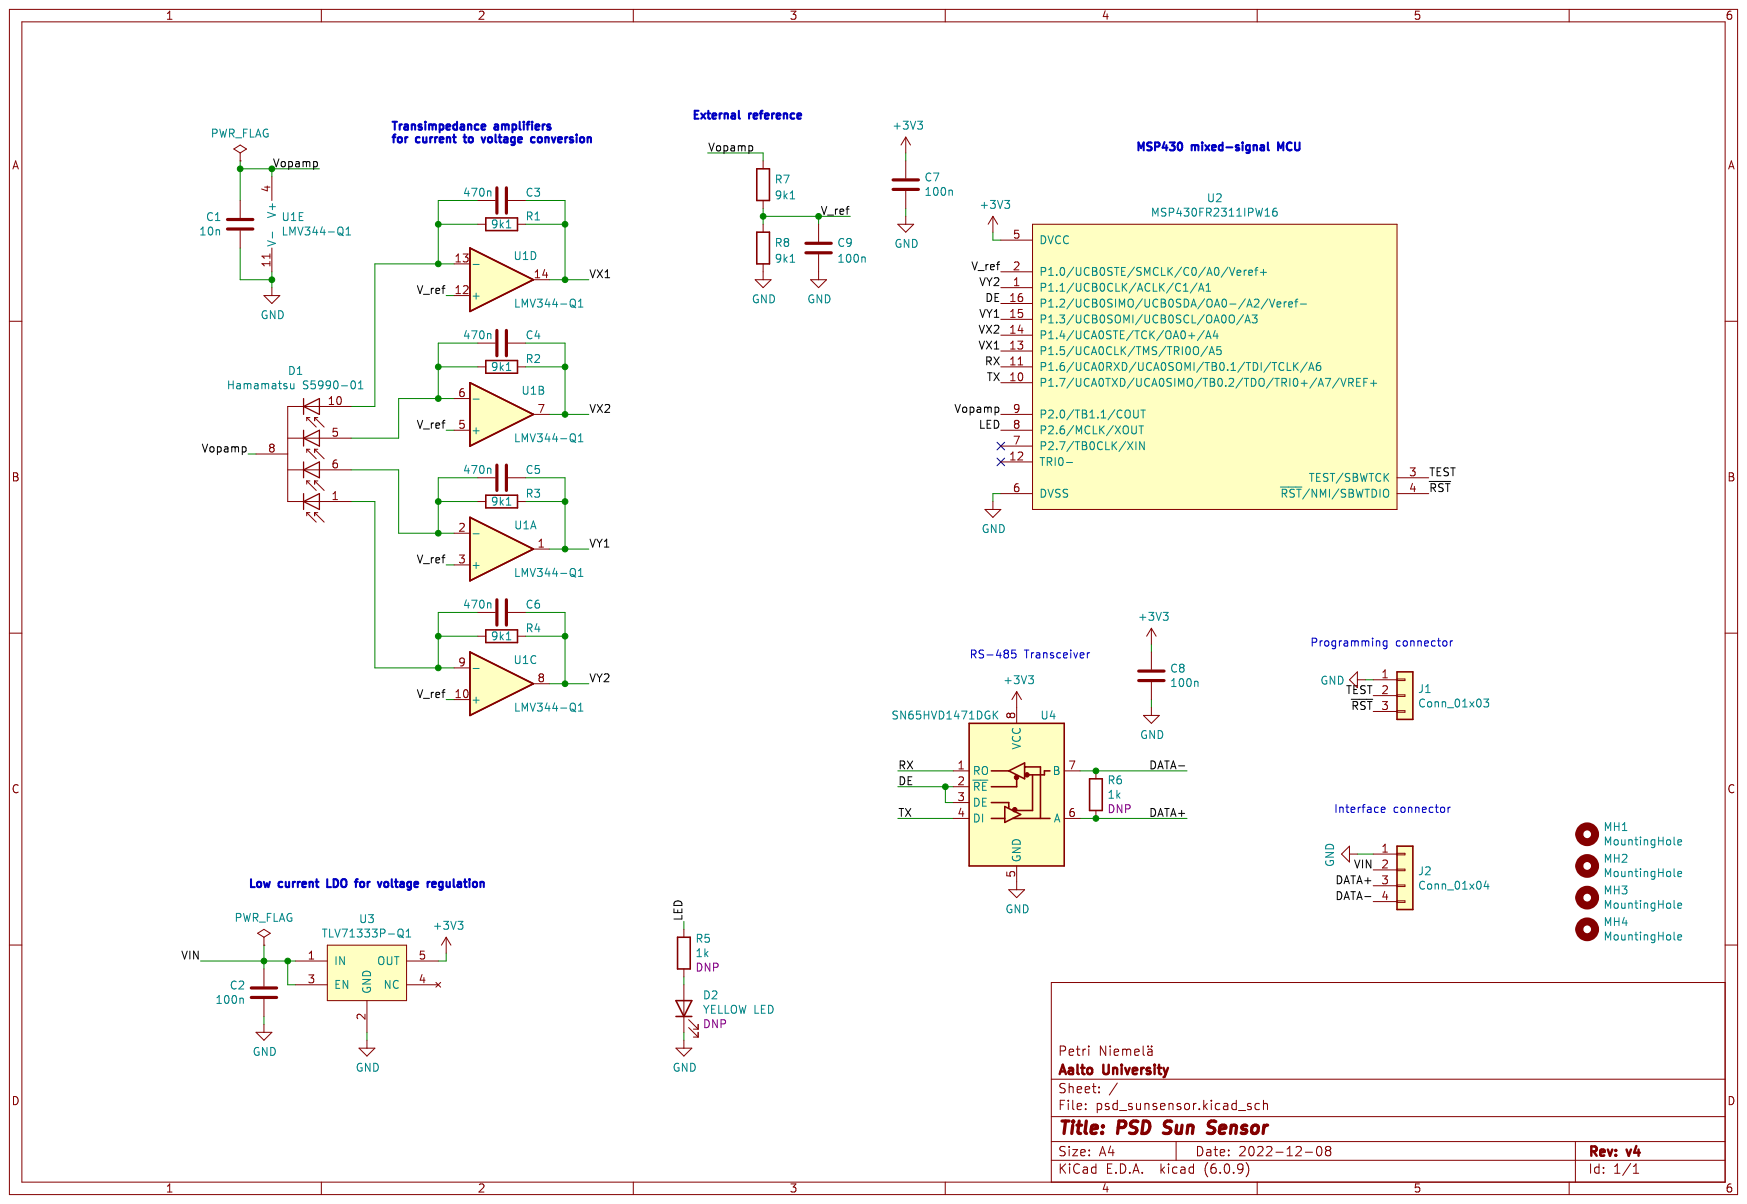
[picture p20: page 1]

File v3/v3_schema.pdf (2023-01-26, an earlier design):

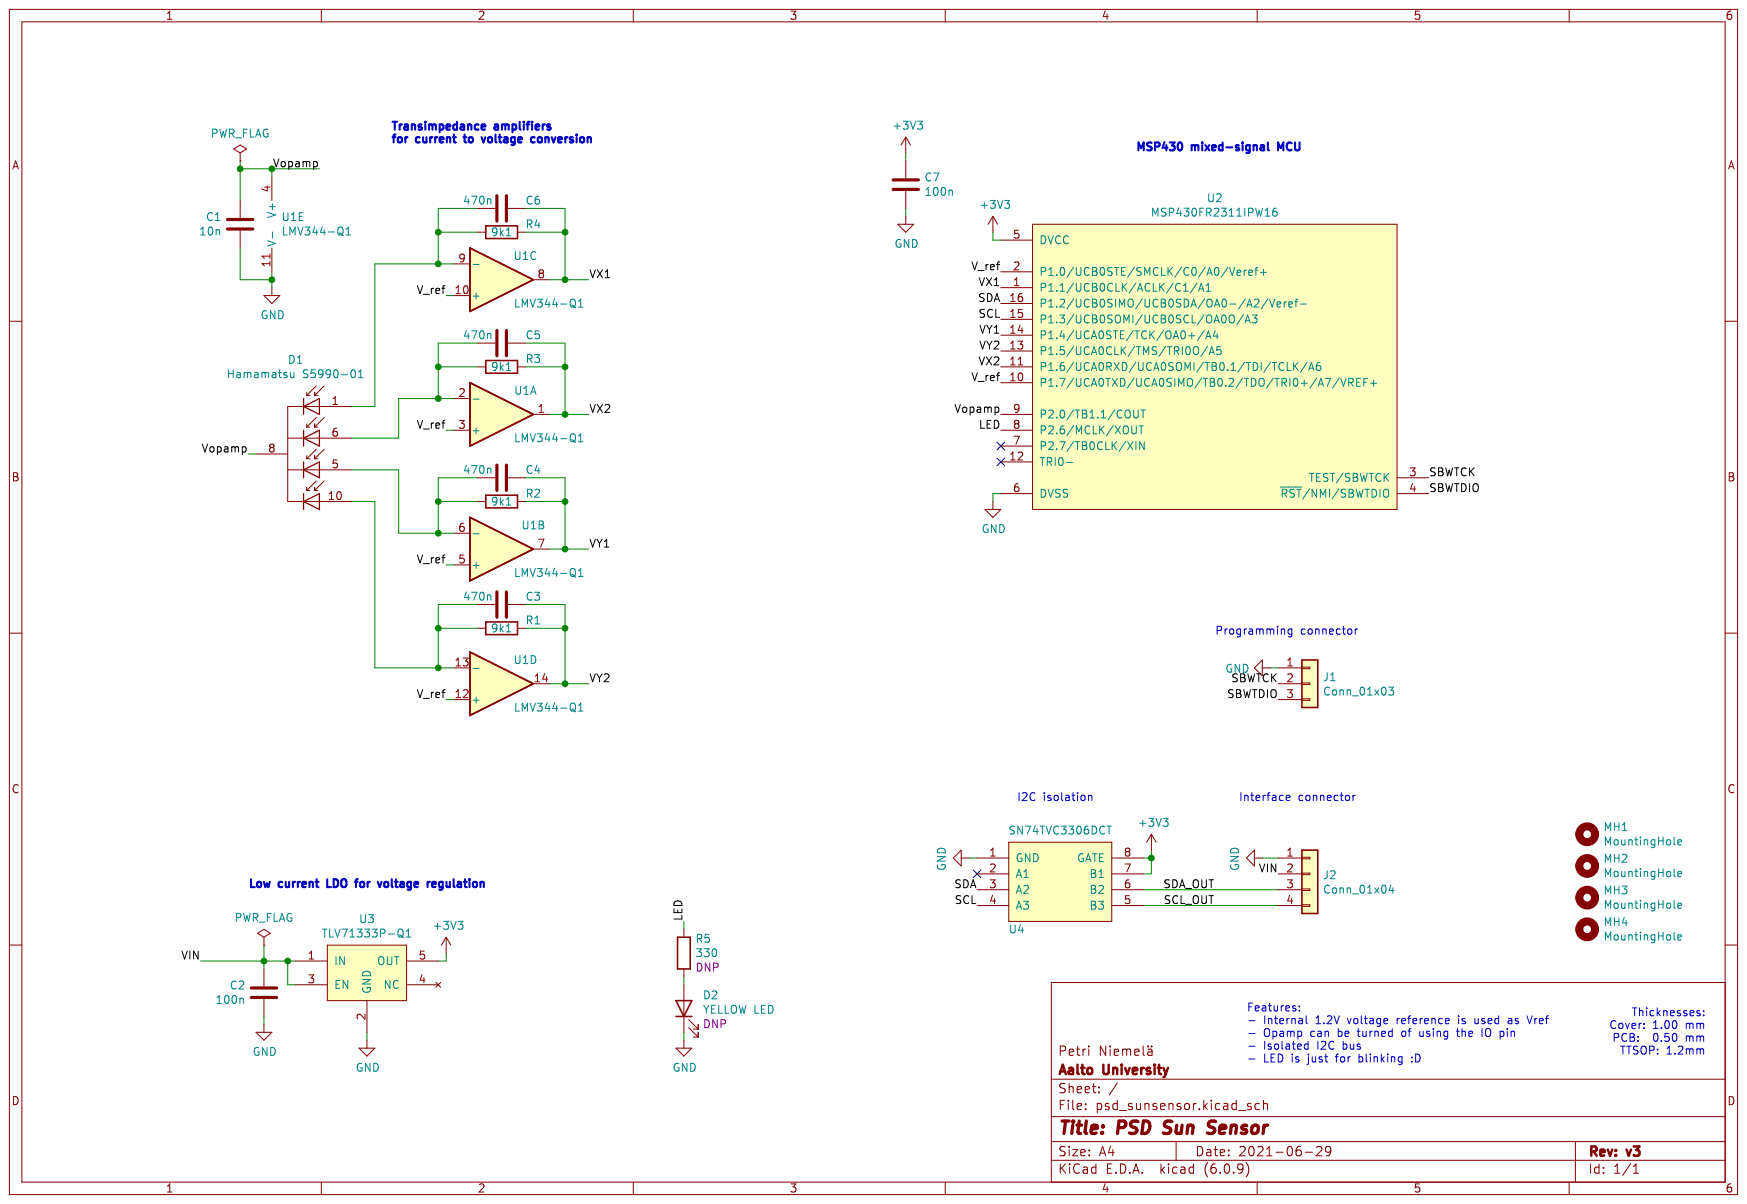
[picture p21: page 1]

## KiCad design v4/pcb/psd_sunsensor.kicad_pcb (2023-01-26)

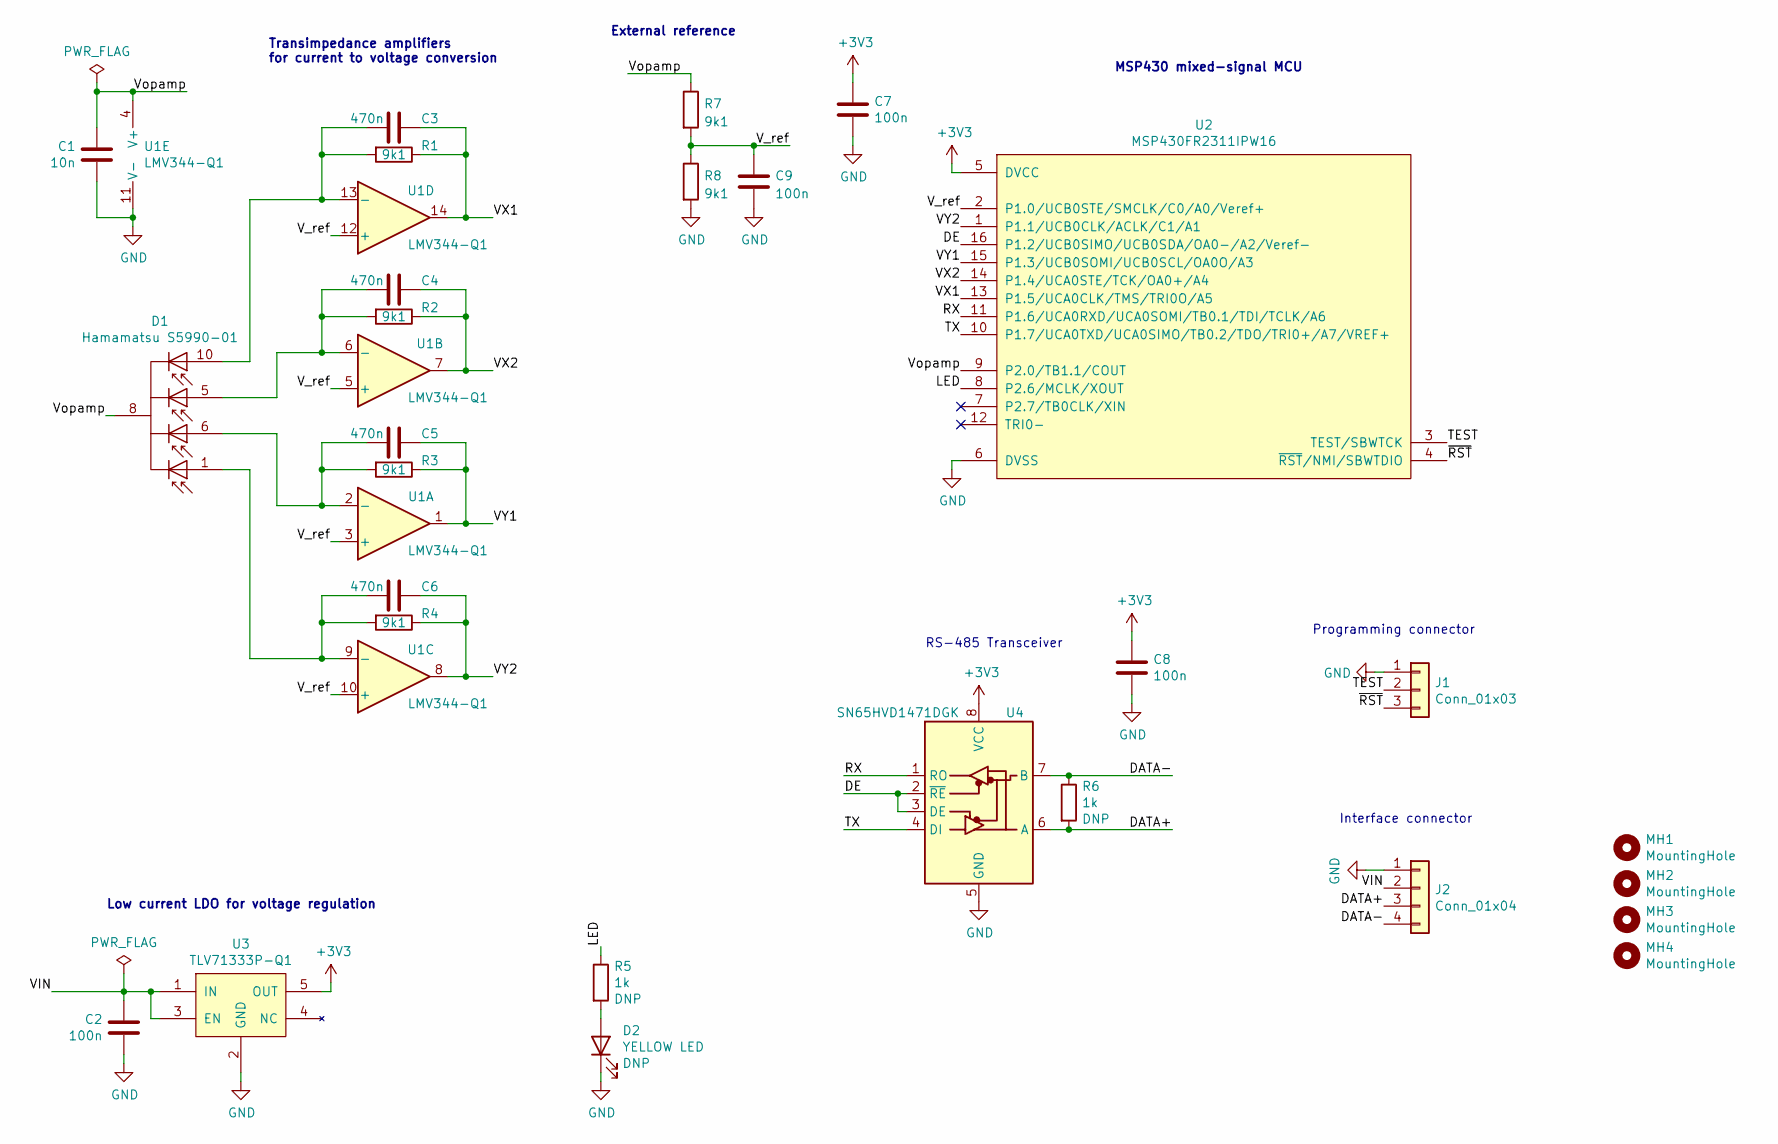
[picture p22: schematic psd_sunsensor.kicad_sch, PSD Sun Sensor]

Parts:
C1: 10n; C_0402_1005Metric
C2, C7, C8, C9: 100n; C_0402_1005Metric
C3, C4, C5, C6: 470n; C_0402_1005Metric
D1: Hamamatsu S5990-01; Hamatsu_S5980
D2: YELLOW LED; LED_0402_1005Metric
J1: Conn_01x03; PinHeader_1x03_P1.27mm_Vertical
J2: Conn_01x04; PinHeader_1x04_P1.27mm_Horizontal
MH1, MH2, MH3, MH4: MountingHole; MountingHole_2.2mm_M2
R1, R2, R3, R4, R7, R8: 9k1; R_0402_1005Metric
R5: 1k; R_0402_1005Metric
R6: 1k; R_0603_1608Metric
U1: LMV344-Q1; TSSOP-14_4.4x5mm_P0.65mm; Mouser 595-LMV344IPWRQ1
U2: MSP430FR2311IPW16; TSSOP-16_4.4x5mm_P0.65mm; Mouser 595-P430FR2311IPW16R
U3: TLV71333P-Q1; SOT-23-5; Mouser 595-TLV71333PQDBVRQ1
U4: SN65HVD1471DGK; VSSOP-8_2.4x2.1mm_P0.5mm

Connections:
+3V3: C7.2, C8.2, U2.5 (DVCC), U3.5 (OUT), U4.8 (VCC)
/DATA+: J2.3, R6.2, U4.6 (A)
/DATA-: J2.4, R6.1, U4.7 (B)
/DE: U2.16 (P1.2/UCB0SIMO/UCB0SDA/OA0-/A2/Veref-), U4.2 (~RE), U4.3 (DE)
/LED: R5.1, U2.8 (P2.6/MCLK/XOUT)
/RX: U2.11 (P1.6/UCA0RXD/UCA0SOMI/TB0.1/TDI/TCLK/A6), U4.1 (RO)
/TEST: J1.2, U2.3 (TEST/SBWTCK)
/TX: U2.10 (P1.7/UCA0TXD/UCA0SIMO/TB0.2/TDO/TRI0+/A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), U4.4 (DI)
/VIN: C2.2, J2.2, U3.1 (IN), U3.3 (EN)
/VX1: C3.1, R1.1, U1.14, U2.13 (P1.5/UCA0CLK/TMS/TRI0O/A5)
/VX2: C4.1, R2.1, U1.7, U2.14 (P1.4/UCA0STE/TCK/OA0+/A4)
/VY1: C5.1, R3.1, U1.1, U2.15 (P1.3/UCB0SOMI/UCB0SCL/OA0O/A3)
/VY2: C6.1, R4.1, U1.8, U2.1 (P1.1/UCB0CLK/ACLK/C1/A1)
/V_ref: C9.2, R7.2, R8.1, U1.3 (+), U1.5 (+), U1.10 (+), U1.12 (+), U2.2 (P1.0/UCB0STE/SMCLK/C0/A0/Veref+)
/Vopamp: C1.2, D1.8 (Cathode), R7.1, U1.4 (V+), U2.9 (P2.0/TB1.1/COUT)
/~RST: J1.3, U2.4 (~RST/NMI/SBWTDIO)
GND: C1.1, C2.1, C7.1, C8.1, C9.1, D2.1 (K), J1.1, J2.1, R8.2, U1.11 (V-), U2.6 (DVSS), U3.2 (GND), U4.5 (GND)
unnamed: C3.2, D1.10 (Anode_Y2), R1.2, U1.13 (-)
unnamed: C4.2, D1.5 (Anode_Y1), R2.2, U1.6 (-)
unnamed: C5.2, D1.6 (Anode_X2), R3.2, U1.2 (-)
unnamed: C6.2, D1.1 (Anode_X1), R4.2, U1.9 (-)
unnamed: D2.2 (A), R5.2

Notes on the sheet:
RS-485 Transceiver
Transimpedance amplifiers for current to voltage conversion
External reference
Low current LDO for voltage regulation
Programming connector
MSP430 mixed-signal MCU
Interface connector

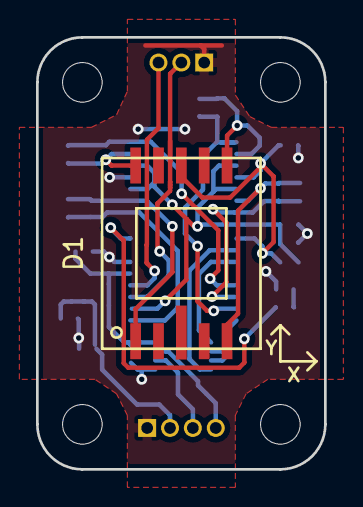
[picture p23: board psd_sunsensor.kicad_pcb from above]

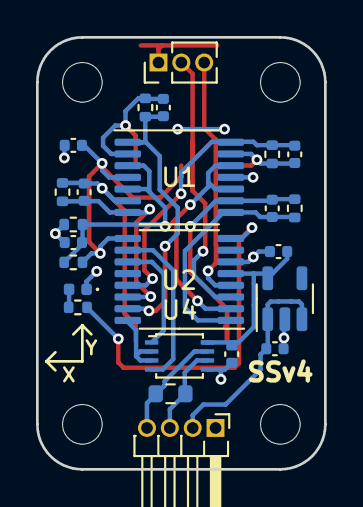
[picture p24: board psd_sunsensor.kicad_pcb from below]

Board: 2 copper layers, 16.0 x 24.0 mm, 29 parts (24 on the bottom side), 22 nets.

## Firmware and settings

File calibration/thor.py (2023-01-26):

#!/usr/bin/env python3
"""
    Thor rotator controller driver.
    Tested on Throw CR1/M-Z7

    Manual: https://www.thorlabs.com/Software/Motion%20Control/APT_Communications_Protocol.pdf
"""

import struct
from typing import NamedTuple, Optional

import serial


#
# List of message IDs
#
MGMSG_HW_DISCONNECT = 0x0002
MGMSG_HW_REQ_INFO = 0x0005
MGMSG_HW_GET_INFO = 0x0006

MGMSG_HW_RESPONSE = 0x0080
MGMSG_HW_RICHRESPONSE = 0x0081

MGMSG_MOD_IDENTIFY = 0x0223

MGMSG_MOD_SET_CHANENABLESTATE = 0x0210
MGMSG_MOD_REQ_CHANENABLESTATE = 0x0211
MGMSG_MOD_GET_CHANENABLESTATE = 0x0212

MGMSG_MOT_SET_POSCOUNTER = 0x0410
MGMSG_MOT_REQ_POSCOUNTER = 0x0411
MGMSG_MOT_GET_POSCOUNTER = 0x0412

MGMSG_MOT_SET_ENCCOUNTER = 0x0409
MGMSG_MOT_REQ_ENCCOUNTER = 0x040A
MGMSG_MOT_GET_ENCCOUNTER = 0x040B

MGMSG_MOT_SET_VELPARAMS = 0x0413
MGMSG_MOT_REQ_VELPARAMS = 0x0414
MGMSG_MOT_GET_VELPARAMS = 0x0415

MGMSG_MOT_SET_JOGPARAMS = 0x0416
MGMSG_MOT_REQ_JOGPARAMS = 0x0417
MGMSG_MOT_GET_JOGPARAMS = 0x0418

MGMSG_MOT_REQ_ADCINPUTS = 0x042B
MGMSG_MOT_GET_ADCINPUTS = 0x042C

MGMSG_MOT_SET_POWERPARAMS = 0x0426
MGMSG_MOT_REQ_POWERPARAMS = 0x0427
MGMSG_MOT_GET_POWERPARAMS = 0x0428

MGMSG_MOT_SET_GENMOVEPARAMS = 0x043A
MGMSG_MOT_REQ_GENMOVEPARAMS = 0x043B
MGMSG_MOT_GET_GENMOVEPARAMS = 0x043C

MGMSG_MOT_SET_MOVERELPARAMS = 0x0445
MGMSG_MOT_REQ_MOVERELPARAMS = 0x0446
MGMSG_MOT_GET_MOVERELPARAMS = 0x0447

MGMSG_MOT_SET_MOVEABSPARAMS = 0x0450
MGMSG_MOT_REQ_MOVEABSPARAMS = 0x0451
MGMSG_MOT_GET_MOVEABSPARAMS = 0x0452

MGMSG_MOT_SET_HOMEPARAMS = 0x0440
MGMSG_MOT_REQ_HOMEPARAMS = 0x0441
MGMSG_MOT_GET_HOMEPARAMS = 0x0442

MGMSG_MOT_SET_LIMSWITCHPARAMS = 0x0423
MGMSG_MOT_REQ_LIMSWITCHPARAMS = 0x0424
MGMSG_MOT_GET_LIMSWITCHPARAMS = 0x0425

MGMSG_MOT_MOVE_HOME = 0x0443
MGMSG_MOT_MOVE_HOMED = 0x0444

MGMSG_MOT_MOVE_RELATIVE = 0x0448
MGMSG_MOT_MOVE_COMPLETED = 0x0464

MGMSG_MOT_MOVE_ABSOLUTE = 0x0453

MGMSG_MOT_MOVE_JOG = 0x046A

MGMSG_MOT_MOVE_VELOCITY = 0x0457

MGMSG_MOT_MOVE_STOP = 0x0465
MGMSG_MOT_MOVE_STOPPED = 0x0466

MGMSG_MOT_SET_BOWINDEX = 0x04F4
MGMSG_MOT_REQ_BOWINDEX = 0x04F5
MGMSG_MOT_GET_BOWINDEX = 0x04F6

MGMSG_MOT_SET_DCPIDPARAMS = 0x04A0
MGMSG_MOT_REQ_DCPIDPARAMS = 0x04A1
MGMSG_MOT_GET_DCPIDPARAMS = 0x04A2

MGMSG_MOT_SET_AVMODES = 0x04B3
MGMSG_MOT_REQ_AVMODES = 0x04B4
MGMSG_MOT_GET_AVMODES = 0x04B5

MGMSG_MOT_SET_POTPARAMS = 0x04B0
MGMSG_MOT_REQ_POTPARAMS = 0x04B1
MGMSG_MOT_GET_POTPARAMS = 0x04B2

MGMSG_MOT_SET_BUTTONPARAMS = 0x04B6
MGMSG_MOT_REQ_BUTTONPARAMS = 0x04B7
MGMSG_MOT_GET_BUTTONPARAMS = 0x04B8

MGMSG_MOT_SET_EEPROMPARAMS = 0x04B9

MGMSG_MOT_SET_POSITIONLOOPPARAMS = 0x04D7
MGMSG_MOT_REQ_POSITIONLOOPPARAMS = 0x04D8
MGMSG_MOT_GET_POSITIONLOOPPARAMS = 0x04D9

MGMSG_MOT_SET_MOTOROUTPUTPARAMS = 0x04DA
MGMSG_MOT_REQ_MOTOROUTPUTPARAMS = 0x04DB
MGMSG_MOT_GET_MOTOROUTPUTPARAMS = 0x04DC

MGMSG_MOT_SET_TRACKSETTLEPARAMS = 0x04E0
MGMSG_MOT_REQ_TRACKSETTLEPARAMS = 0x04E1
MGMSG_MOT_GET_TRACKSETTLEPARAMS = 0x04E2


class ThorResponse(NamedTuple):
    message_id: int
    param1: int
    param2: int
    data: bytes

class VelocityParameters(NamedTuple):
    channel: int # The channel being addressed
    min_velocity: int # The minimum (start) velocity in encoder counts / sec
    accleration: int # The acceleration in encoder counts / sec^2
    max_velocity: int # The maximum (final) velocity in encoder counts / sec

class JogParameters(NamedTuple):
    channel: int # The channel being addressed
    mode: int # Jogging mode (TODO)
    step_size: int
    min_velocity: int # minimum velocity
    accleration: int # Acceleration
    max_velocity: int # Maximum velocity
    stop_mode: int # Stopping mode (TODO)

class HomeParameters(NamedTuple):
    channel: int # The channel being addressed
    home_dir: int # The direction sense for a move to Home, either: 1 - forward/Positive or  2 - reverse/negative.
    limit_switch: int # The limit switch associated with the home position: 1 - hardware reverse or 4 - hardware forward
    home_velocity: int # The homing velocity.
    offset_distance: int # The distance of the Home position from the Home Limit Switch.

class PIDParameters(NamedTuple):
    channel: int # The channel being addressed
    p: int # The proportional gain
    i: int # The integral gain
    d: int # The differential gain
    integral_limit: int # The Integral Limit parameter is used to cap the value of the Integrator to prevent runaway of the integral sum
    filter_control: int # Identifies which of the above parameters are applied by

class ButtonParameters(NamedTuple):
    channel: int # The channel being addressed
    mode: int # 1 = the buttons are used to jog the motor (JogParameters). 2 =  each button can be programmed with a different position value
    position_1: int # The position (in encoder counts) to which the motor will move when the top button is pressed.
    position_2: int # The position (in encoder counts) to which the motor will move when the bottom button is pressed.
    timeout_1: int # The time in ms that button 1 must be depressed.
    timeout_2: int # The time in ms that button 2 must be depressed.

class PotentiometerParameters(NamedTuple):
    channel: int # The channel being addressed
    zero_wnd: int # The deflection from the mid position (in ADC counts 0 to 127) before motion can start
    vel1: int # The velocity (in encoder counts /sec) to move when between Wnd0 and PotDef1
    wnd1: int # The deflection from the mid position (in ADC counts, Wnd0 to 127) to apply Vel1
    vel2: int # The velocity (in encoder counts /sec) to move when between PotDef1 and PotDef2
    wnd2: int # The deflection from the mid position (in ADC counts, PotDef1 to 127) to apply Vel2
    vel3: int # The velocity (in encoder counts/sec) to move when between PotDef2 and PotDef3
    wnd3: int # The deflection from the mid position (in ADC counts PotDef2 to 127) to apply Vel3
    vel4: int # The velocity (in encoder counts /sec) to move when beyond PotDef3



class ThorRotator:

    EncCnt = 1638  # counts per degree

    velocity_scale = 36650
    acceleration_scale = 95.276

    print_packets = False


    def __init__(self, device: str="/dev/ttyUSB0", _serial=None):
        """
        Initialize new connection to Thor rotator

        Args:
            device: The rotator serial port
        """

        if _serial is None:
            self._serial = serial.Serial(device, baudrate=115200, timeout=0.1)
        else:
            self._serial = _serial

        self.dest = 0x50
        self.src = 0x01


    def degrees(self, count: int) -> float:
        """
        Convert encoder count to degrees.
        """
        return count / self.EncCnt


    def counts(self, degrees: float) -> int:
        """
        Convert degrees to encoder count.
        """
        return int(degrees * self.EncCnt)


    def _send(self,
            message_id: int,
            param1: Optional[int]=0,
            param2: Optional[int]=0,
            data: Optional[bytes]=None
        ) -> None:
        """
        Contruct a command and send it.

        Args:
            message_id: Message ID
            param1:
            param2:
            data: Arbitrary data
        """

        if data is not None:
            msg = struct.pack("<HHBB", message_id, len(data), self.dest | 0x80, self.src) + data
        else:
            msg = struct.pack("<HBBBB", message_id, param1, param2, self.dest, self.src)

        if self.print_packets:
            print("TX:", msg)
        self._serial.write(msg)


    def _get(self, message_id: int, length: int) -> bytes:
        """
        """
        raise NotImplementedError()
        msg = struct.pack("<HHBB", message_id, length, self.dest | 0x80, self.src)
        if self.print_packets:
            print("TX:", msg)

        self._serial.write(msg)

        data = self._serial.read(length)
        if self.print_packets:
            print("RX:", data)
        return data


    def _request(self, **kwargs) -> ThorResponse:
        """
        Send and receive
        """
        self._send(**kwargs)
        return self._receive()


    def _receive(self, timeout: Optional[int]=None) -> ThorResponse:
        """
        Wait for response from the device.

        Returns:
            ThorResponse object
        """
        t = self._serial.timeout
        try:
            if timeout is not None:
                self._serial.timeout = timeout
            hdr = self._serial.read(6)
        finally:
            self._serial.timeout = t

        if self.print_packets:
            print("RX:", hdr)

        if len(hdr) != 6:
            raise serial.SerialTimeoutException()
        message_id, param1, param2, dest, src = struct.unpack(">HBBBB", hdr)

        if 0x80 & dest:
            # Arbitrary length frame
            data_len = param1 | (param2 << 8)
            data = self._serial.read(data_len)
            if self.print_packets:
                print("   ", data)
            return ThorResponse(message_id, None, None, data)

        return ThorResponse(message_id, param1, param2, None)


    def identify(self, channel: int) -> None:
        """
        Identify the rotator by blinking the LED.
        """
        self._send(message_id=MGMSG_MOD_IDENTIFY)


    def set_channel_state(self, channel: int, state: bool=True) -> None:
        """
        Enable/disable channel

        Args:
            channel: The channel being addressed.
        """
        self._send(
            message_id=MGMSG_MOD_SET_CHANENABLESTATE,
            param1=channel,
            param2=(1 if state else 2)
        )


    def get_channel_state(self, channel: int) -> bool:
        """
        Get channel state

        Args:
            channel: The channel being addressed.

        Returns:
            State as boolean.
        """
        rsp = self._request(
            message_id=MGMSG_MOD_REQ_CHANENABLESTATE,
            data=struct.pack("B", channel),
        )
        assert channel == rsp.param1
        return rsp.param2 == 1


    def get_infos(self) -> bytes:
        """
        Get hardware information

        Returns:
            Hardware information as bytes.
        """
        rsp = self._request(message_id=MGMSG_HW_REQ_INFO)
        return rsp.data


    def set_position(self, channel: int, position: int) -> None:
        """
        Set position counter

        Args:
            channel: The channel being addressed.
            position: Position counter
        """

        self._send(
            message_id=MGMSG_MOT_SET_ENCCOUNTER,
            data=struct.pack("<Hi", channel, position)
        )


    def get_position(self) -> int:
        """
        Get position counter

        Returns:
            Current position as encoder count
        """

        rsp = self._request(message_id=MGMSG_MOT_REQ_ENCCOUNTER)
        channel_, position = struct.unpack("<Hi", rsp.data)
        return position


    def set_velocity(self, channel: int, min_vel: int, accl: int, max_vel: int) -> None:
        """
        Set velocity parameters

        Args:
            channel: The channel being addressed.
        """

        self._send(
            message_id=MGMSG_MOT_SET_VELPARAMS,
            data=struct.pack("<HIII", channel, min_vel, accl, max_vel)
        )


    def get_velocity(self, channel: int) -> VelocityParameters:
        """
        Get velocity paramters

        Args:
            channel: The channel being addressed.

        Returns:

        """
        rsp = self._request(
            message_id=MGMSG_MOT_REQ_VELPARAMS,
            param1=channel
        )
        return VelocityParameters(*struct.unpack("<HIII", rsp.data))


    def set_relative_distance(self, channel: int, distance: int) -> None:
        """
        Set relative relative distance.

        Args:
            channel: The channel being addressed.
            distance: Relative distance
        """

        self._send(
            message_id=MGMSG_MOT_SET_MOVERELPARAMS,
            data=struct.pack("<Hi", channel, distance)
        )


    def get_relative_distance(self, channel: int) -> int:
        """
        Get relative distance.

        Args:
            channel: The channel being addressed.

        Returns:
            relative distance is returned as an integer.
        """

        rsp = self._request(
            message_id=MGMSG_MOT_REQ_MOVERELPARAMS,
            param1=channel
        )
        channel_, rel = struct.unpack("<Hi", rsp.data)
        assert channel == channel_
        return rel


    def set_absolute_postion(self, channel: int, position: int) -> None:
        """
        Set absolute position.

        Args:
            channel: The channel being addressed.
            position: Absolute postion
        """

        self._send(
            message_id=MGMSG_MOT_SET_MOVEABSPARAMS,
            data=struct.pack("<Hi", channel, int(position))
        )


    def get_absolute_position(self, channel: int) -> int:
        """
        Get absolute position

        Args:
            channel: The channel being addressed.

        Returns:
            Absolute position as integer
        """

        rsp = self._request(
            message_id=MGMSG_MOT_REQ_MOVEABSPARAMS,
            param1=channel
        )
        channel_, position = struct.unpack("<Hi", rsp.data)
        assert channel == channel_
        return position


    def set_jog(self, channel: int, param: JogParameters) -> None:
        """
        Set jogging parameters

        Args:
            channel: The channel being addressed.
            param: Jog paramters
        """

        self._send(
            message_id=MGMSG_MOT_SET_JOGPARAMS,
            data=struct.pack("<HHIIIIH", channel, param.jog_mode, param.min_velocity, param.accleration, param.max_velocity, param.stop_mode)
        )


    def get_jog(self, channel: int) -> JogParameters:
        """
        Get Jog parameters

        Args:
            channel: The channel being addressed.

        Returns:
            JogParameters object
        """
        rsp = self._request(
            message_id=MGMSG_MOT_REQ_JOGPARAMS,
            param1=channel
        )
        return JogParameters(*struct.unpack("<HHIIIIH", rsp.data))


    def set_pot(self, channel: int, param: PotentiometerParameters) -> None:
        """
        Set pot parameters

        Args:
            channel: The channel being addressed.
            param: Potentiometer parameters as PotentiometerParameters object
        """

        self._send(
            message_id=MGMSG_MOT_SET_POTPARAMS,
            data=struct.pack("<HHIHIHIHI", channel, param.vel1, param.wnd1, param.vel2, param.wnd2, param.vel3, param.wnd3, param.vel4)
        )


    def get_pot(self, channel: int) -> PotentiometerParameters:
        """
        Get pot parameters

        Args:
            channel: The channel being addressed.

        Returns:
            PotentiometerParameters object
        """
        rsp = self._request(
            message_id=MGMSG_MOT_REQ_POTPARAMS,
            param1=channel
        )
        return PotentiometerParameters(*struct.unpack("<HHIHIHIHI", rsp.data))


    def set_button_parameters(self, channel: int, param: ButtonParameters) -> None:
        """
        Set button parameters

        Args:
            channel: The channel being addressed.
            param: Button paramters
        """

        self._send(
            message_id=MGMSG_MOT_SET_BUTTONPARAMS,
            data=struct.pack("<HHiiHH", param.channel, param.mode, param.position_1, param.position_2, param.timeout_1, param.timeout_2)
        )


    def get_button_parameters(self, channel: int) -> ButtonParameters:
        """
        Get button parameters.

        Args:
            channel: The channel being addressed.

        Returns:
            ButtonParameters object containing the received parameters.
        """

        rsp = self._request(
            message_id=MGMSG_MOT_REQ_BUTTONPARAMS,
            param1=channel
        )
        return ButtonParameters(*struct.unpack("<HHiiHH", rsp.data))


    def set_bow(self, channel: int, bow_index: int) -> None:
        """
        Set bow index

        Args:
            channel: The channel being addressed.
            bow_index: Bow index
        """

        self._send(
            message_id=MGMSG_MOT_SET_BOWINDEX,
            data=struct.pack("<HH", channel, bow_index)
        )


    def get_bow(self, channel: int) -> int:
        """
        Get bow index

        Args:
            channel: The channel being addressed.

        Returns:
            Bow index as integer
        """

        rsp = self._request(
            message_id=MGMSG_MOT_REQ_BOWINDEX,
            param1=channel
        )
        channel, bow_index = struct.unpack("<HH", rsp.data)
        return bow_index


    def set_pid(self, channel: int, param: PIDParameters) -> None:
        """
        Set PID parameters

        Args:
            channel: The channel being addressed.
            param:
        """

        self._send(
            message_id=MGMSG_MOT_SET_DCPIDPARAMS,
            data=struct.pack("<HIIIIH", channel, param.p, param.i, param.d, param.limit, param.filt)
        )


    def get_pid(self, channel: int) -> PIDParameters:
        """
        Get PID parameters

        Args:
            channel: The channel being addressed.

        Returns:
            PIDParameters object
        """

        rsp = self._request(message_id=MGMSG_MOT_REQ_DCPIDPARAMS, param1=channel)
        return PIDParameters(*struct.unpack("<HIIIIH", rsp.data))


    def get_home(self, channel: int) -> HomeParameters:
        """
        Get home parameters.

        Args:
            channel: The channel being addressed.

        Returns:
            HomeParameters object
        """

        rsp = self._request(
            message_id=MGMSG_MOT_REQ_HOMEPARAMS,
            param1=channel
        )
        return HomeParameters(*struct.unpack("<HHHIi", rsp.data))


    def move_home(self, channel: int):
        """
        Move to home.

        Args:
            channel: The channel being addressed.
        """
        self._send(
            message_id=MGMSG_MOT_MOVE_HOME,
            param1=channel
        )
        self._receive(timeout=120) # Wait for move done



    def move_relative(self, channel: int, distance: Optional[int]=None) -> None:
        """
        Move relative distance

        Args:
            channel: The channel being addressed.
            distance: Distance to be moved (Optional)
        """
        if distance is not None:
            self.set_relative_distance(channel, distance)

        self._send(MGMSG_MOT_MOVE_RELATIVE, param1=channel)
        self._receive(timeout=120) # Wait for move done


    def move_absolute(self, channel: int, position: Optional[int]=None) -> None:
        """
        Move to abosule position

        Args:
            channel: The channel being addressed.
            pos: Absolute postion to move.
        """
        if position is not None:
            self.set_absolute_postion(channel, position)

        self._send(MGMSG_MOT_MOVE_ABSOLUTE, param1=channel)
        self._receive(timeout=120) # Wait for move done


    def move_velocity(self, channel: int, direction: int) -> None:
        """
        Move forward/background

        Args:
            channel: The channel being addressed.
            direction: Movement direction
        """
        self._send(
            message_id=MGMSG_MOT_MOVE_VELOCITY,
            param1=channel,
            param2=direction
        )


    def stop(self, channel: int, stop_mode: int=2) -> None:
        """
        Stop any type of motor move (relative, absolute, homing or
        move at velocity) on the specified motor channel.

        Args:
            channel: The channel being addressed.
            stop_mode: either an immediate (abrupt) or profiles tops.
                1 = Stop immediately
                2 = Stop in a controller (profiled) manner
        """

        self._send(
            message_id=MGMSG_MOT_MOVE_STOP,
            param1=channel,
            param2=stop_mode
        )


    def move_jog(self, channel: int, direction: int) -> None:
        """
        Start a jog move on the specified motor channel.

        Args:
            channel: The channel being addressed
            direction: The direction to Jog. 1 = forward, 2 = reverse
        """

        self._send(
            message_id=MGMSG_MOT_MOVE_JOG,
            param1=channel,
            param2=direction,
        )
        self._receive(timeout=120) # Wait for move done

if __name__ == "__main__":

    import argparse
    parser = argparse.ArgumentParser(description="ThorLabs rotator control tool")
    parser.add_argument('--device', '-D', default="/dev/ttyUSB0", help="Serial device")
    parser.add_argument('--channel', '-c', type=int, default=1, help="Channel")
    args = parser.parse_args()

    thor = ThorRotator(device=args.device)

    def print_enum(obj):
        print(f"# {obj.__class__.__name__}:")
        for name, value in obj._asdict().items():
            print(f"{name:>20}: {value!r}")
        print()


    print(f"Channel #{args.channel}")
    print(f"State: {thor.get_channel_state(args.channel)}")
    print(f"Position: {thor.get_position()}")
    print_enum(thor.get_home(args.channel))
    print_enum(thor.get_pid(args.channel))
    print_enum(thor.get_velocity(args.channel))
    print_enum(thor.get_jog(args.channel))
    print_enum(thor.get_pot(args.channel))
    print_enum(thor.get_button_parameters(args.channel))

    #thor.set_position(args.channel, 0)
    #thor.move_home(args.channel)
    thor.move_absolute(args.channel, 50*thor.EncCnt)
    #thor.move_relative(args.channel, 50)

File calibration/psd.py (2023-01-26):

#!/usr/bin/env python3
"""
    Control PSD Sun Sensor over FTDI 232H USB interface cable.
"""

import sys
import time
import struct
from typing import List, NamedTuple, Tuple, Union

from pyftdi.i2c import I2cController, I2cPort, I2cNackError


__all__ = [
    "RawMeasurement",
    "PointMeasurement",
    "VectorMeasurement"
    "AngleMeasurement",
    "Calibration",
]


# Command codes:
PSD_CMD_STATUS          = 0x01
PSD_CMD_GET_RAW         = 0x03
PSD_CMD_GET_POINT       = 0x04
PSD_CMD_GET_VECTOR      = 0x05
PSD_CMD_GET_ANGLES      = 0x06
PSD_CMD_GET_ALL         = 0x07
PSD_CMD_GET_TEMPERATURE = 0x08
PSD_CMD_SET_CALIBRATION = 0x10
PSD_CMD_GET_CALIBRATION = 0x11
PSD_CMD_SET_I2C_ADDRESS = 0xE8

# Response codes:
PSD_RSP_OK              = 0xF0
PSD_RSP_SLEEP           = 0xF1
PSD_RSP_RAW             = 0xF3
PSD_RSP_POINT           = 0xF4
PSD_RSP_VECTOR          = 0xF5
PSD_RSP_ANGLES          = 0xF6
PSD_RSP_ALL             = 0xF7
PSD_RSP_TEMPERATURE     = 0xF8
PSD_RSP_CALIBRATION     = 0xFA
PSD_RSP_UNKNOWN_COMMAND = 0xFD
PSD_RSP_INVALID_PARAM   = 0xFE
PSD_RSP_ERROR           = 0xFF


# Structures for data
class RawMeasurement(NamedTuple):
    """
    A raw PSD diode current measurement.
    Measured current are between 0 and 1024
    """
    x1: int
    x2: int
    y1: int
    y2: int

class PointMeasurement(NamedTuple):
    """
    Calculated light point position measurement
    """
    x: int
    y: int
    intensity: int

class VectorMeasurement(NamedTuple):
    """
    Calculated sun direction vector point position measurement
    """
    x: int
    y: int
    z: int
    intensity: int

class AngleMeasurement(NamedTuple):
    """
    Calculated sun direction as angles.
    """
    rx: float
    ry: float
    intensity: int

class Calibration(NamedTuple):
    """
    PSD Calibration value struct
    """
    offset_x: int
    offset_y: int
    height: int
    samples: int
    temp_offset: int



class PSDSunSensor:
    """
    Class to communicate to single PSD Sun Sensor over I2C.
    """

    def __init__(self, addr: int, i2c: I2cController = None):
        """
        Initialize connection to PSD Sun Sensor
        aka opens FTDI 232H I2C controller and and I2C port for the sensor.

        Args:
            addr: Sensor I2C address
            i2c: FTDI I2C Controller object. If not given a new controller
                object will be initialized with default values.
        """
        if i2c is None:
            i2c = I2cController()
            i2c.configure("ftdi://ftdi:232h/1", frequency=50e3)
        self._i2c = i2c
        self._port = i2c.get_port(addr)


    def get_raw(self) -> RawMeasurement:
        """
        Read raw measurements from the sun sensor.

        Returns:
            A RawMeasurement object
        """

        self._port.write(struct.pack("B", PSD_CMD_GET_RAW))
        time.sleep(0.01)

        rsp = self._port.read(9)
        if rsp[0] != PSD_RSP_RAW:
            raise RuntimeError(f"Sensor responded error 0x{rsp[0]:02x}")
        return RawMeasurement(*struct.unpack("<xHHHH", rsp))


    def get_point(self) -> PointMeasurement:
        """
        Read light point measurement from the sun sensor.

        Returns:
            A PointMeasurement object
        """

        self._port.write(struct.pack("B", PSD_CMD_GET_POINT))
        time.sleep(0.01)

        rsp = self._port.read(7)
        if rsp[0] != PSD_RSP_POINT:
            raise RuntimeError(f"Sensor responded error 0x{rsp[0]:02x}")
        return PointMeasurement(*struct.unpack("<xhhH", rsp))


    def get_vector(self) -> VectorMeasurement:
        """
        Read light point measurement from the sun sensor.

        Returns:
            A VectorMeasurement object
        """

        self._port.write(struct.pack("B", PSD_CMD_GET_VECTOR))
        time.sleep(0.01)

        rsp = self._port.read(9)
        if rsp[0] != PSD_RSP_VECTOR:
            raise RuntimeError(f"Sensor responded error 0x{rsp[0]:02x}")
        return VectorMeasurement(*struct.unpack("<xhhhH", rsp))


    def get_angles(self) -> AngleMeasurement:
        """
        Read angle measuremnt from the sun sensor

        Returns:
            A AngleMeasurement object
        """

        self._port.write(struct.pack("B", PSD_CMD_GET_ANGLES))
        time.sleep(0.02)

        rsp = self._port.read(7)
        if rsp[0] != PSD_RSP_ANGLES:
            raise RuntimeError(f"Sensor responded error 0x{rsp[0]:02x}")
        meas = struct.unpack("<xHHH", rsp)
        return AngleMeasurement(meas[0] / 10, meas[1] / 10, meas[2])


    def get_all(self) -> Tuple[RawMeasurement, PointMeasurement, AngleMeasurement]:
        """
        Read all three measurement structs from the sun sensor

        Returns:
            A tuple containing RawMeasurement, PointMeasurement and AngleMeasurement object
        """

        self._port.write(struct.pack("B", PSD_CMD_GET_ALL))
        time.sleep(0.2)

        rsp = self._port.read(21)
        if rsp[0] != PSD_RSP_ALL:
            raise RuntimeError(f"Sensor responded error 0x{rsp[0]:02x}")

        raw   =   RawMeasurement(*struct.unpack("<HHHH", rsp[1:9]))
        point = PointMeasurement(*struct.unpack("<hhH",  rsp[9:15]))
        angle = AngleMeasurement(*struct.unpack("<hhH",  rsp[15:21]))
        return raw, point, angle



    def get_temperature(self) -> float:
        """
        Read sun sensor's temperature

        Returns:
            Temperature reading in Celcius degrees.
        """

        self._port.write(struct.pack("B", PSD_CMD_GET_TEMPERATURE))

        rsp = self._port.read(3)
        if rsp[0] != PSD_RSP_TEMPERATURE:
            raise RuntimeError(f"Sensor responded error 0x{rsp[0]:02x}")
        return struct.unpack("<xh", rsp)[0] / 10.0


    def set_calibration(self, calib: Union[Calibration, Tuple]) -> None:
        """
        Write sun sensor calibration values

        Args:
            calib: A calibration object a tuple containing the calibration values.

        Example:
            set_calibration(sensor, Calibration(offset_x=0, offset_y=0, height=670, samples=1, temp_offset=650))
        """

        self._port.write(struct.pack("<Bhhhhh", PSD_CMD_SET_CALIBRATION, *calib))
        #time.sleep(0.05)

        rsp = self._port.read(1)
        if rsp[0] != PSD_RSP_OK:
            raise RuntimeError(f"Sensor responded error 0x{rsp[0]:02x}")


    def get_calibration(self) -> Calibration:
        """
        Read sunsensor's temperature sensor.

        Returns:
            A Calibration object
        """

        self._port.write(struct.pack("B", PSD_CMD_GET_CALIBRATION))
        #time.sleep(0.05)

        rsp = self._port.read(11)
        if rsp[0] != PSD_RSP_CALIBRATION:
            raise RuntimeError(f"Sensor responded error 0x{rsp[0]:02x}")
        return Calibration(*struct.unpack("<xhhhhh", rsp))


    def set_lut(self, lut: List[int]) -> None:
        """
        Write the Position to angle look-up-table in the memory.
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

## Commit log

2023-01-26 Add v3 and v4 design files
    [BOM.xlsx, PSD Sun Sensor.f3z, psd_sun_sensor.step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]
2026-03-24 Update README with performance article link
    Added a reference to the performance and testing article for the PSS sun sensor.
